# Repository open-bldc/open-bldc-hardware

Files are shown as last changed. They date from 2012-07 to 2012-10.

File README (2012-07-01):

This project aims to create a fully open-source Brushless Drive Controller.

This repository contains all current and past hardware designs. Please refer to the open-bldc repository for the source code.

Licensing
---------
All sourcecode is licensed under GPL version 3 or later, all circuitry designs
and pcb layouts are available as original source files and licensed under
CreativeCommons BY-SA 3.0.

Feel free to use everything here as you wish! :)

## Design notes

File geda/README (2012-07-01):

-------------------------------------------------------------------------------
README
-------------------------------------------------------------------------------

This is an effort to re-implement the Open-BLDC hardware descriptions
(schematics and PCB layouts) using the open-source tools gEDA/pcb.

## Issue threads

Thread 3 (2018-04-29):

modular ESC

mkeyno, 2018-04-29:
Hi, sorry to open ticket for my question , actually I intend to made modular ESC in way that controller + gate driver is separated from Mosfets pcb , hence I could increase module ampere by adding parallel Mosfet in the Mosfets pcb, I really appreciated to have your advise or if you know open HW/SW sources let me know

jegb, 2018-04-29:
you could break the modules down as in[ this NXP paper ](https://www.nxp.com/docs/en/user-guide/3PHLVPSUM.pdf)

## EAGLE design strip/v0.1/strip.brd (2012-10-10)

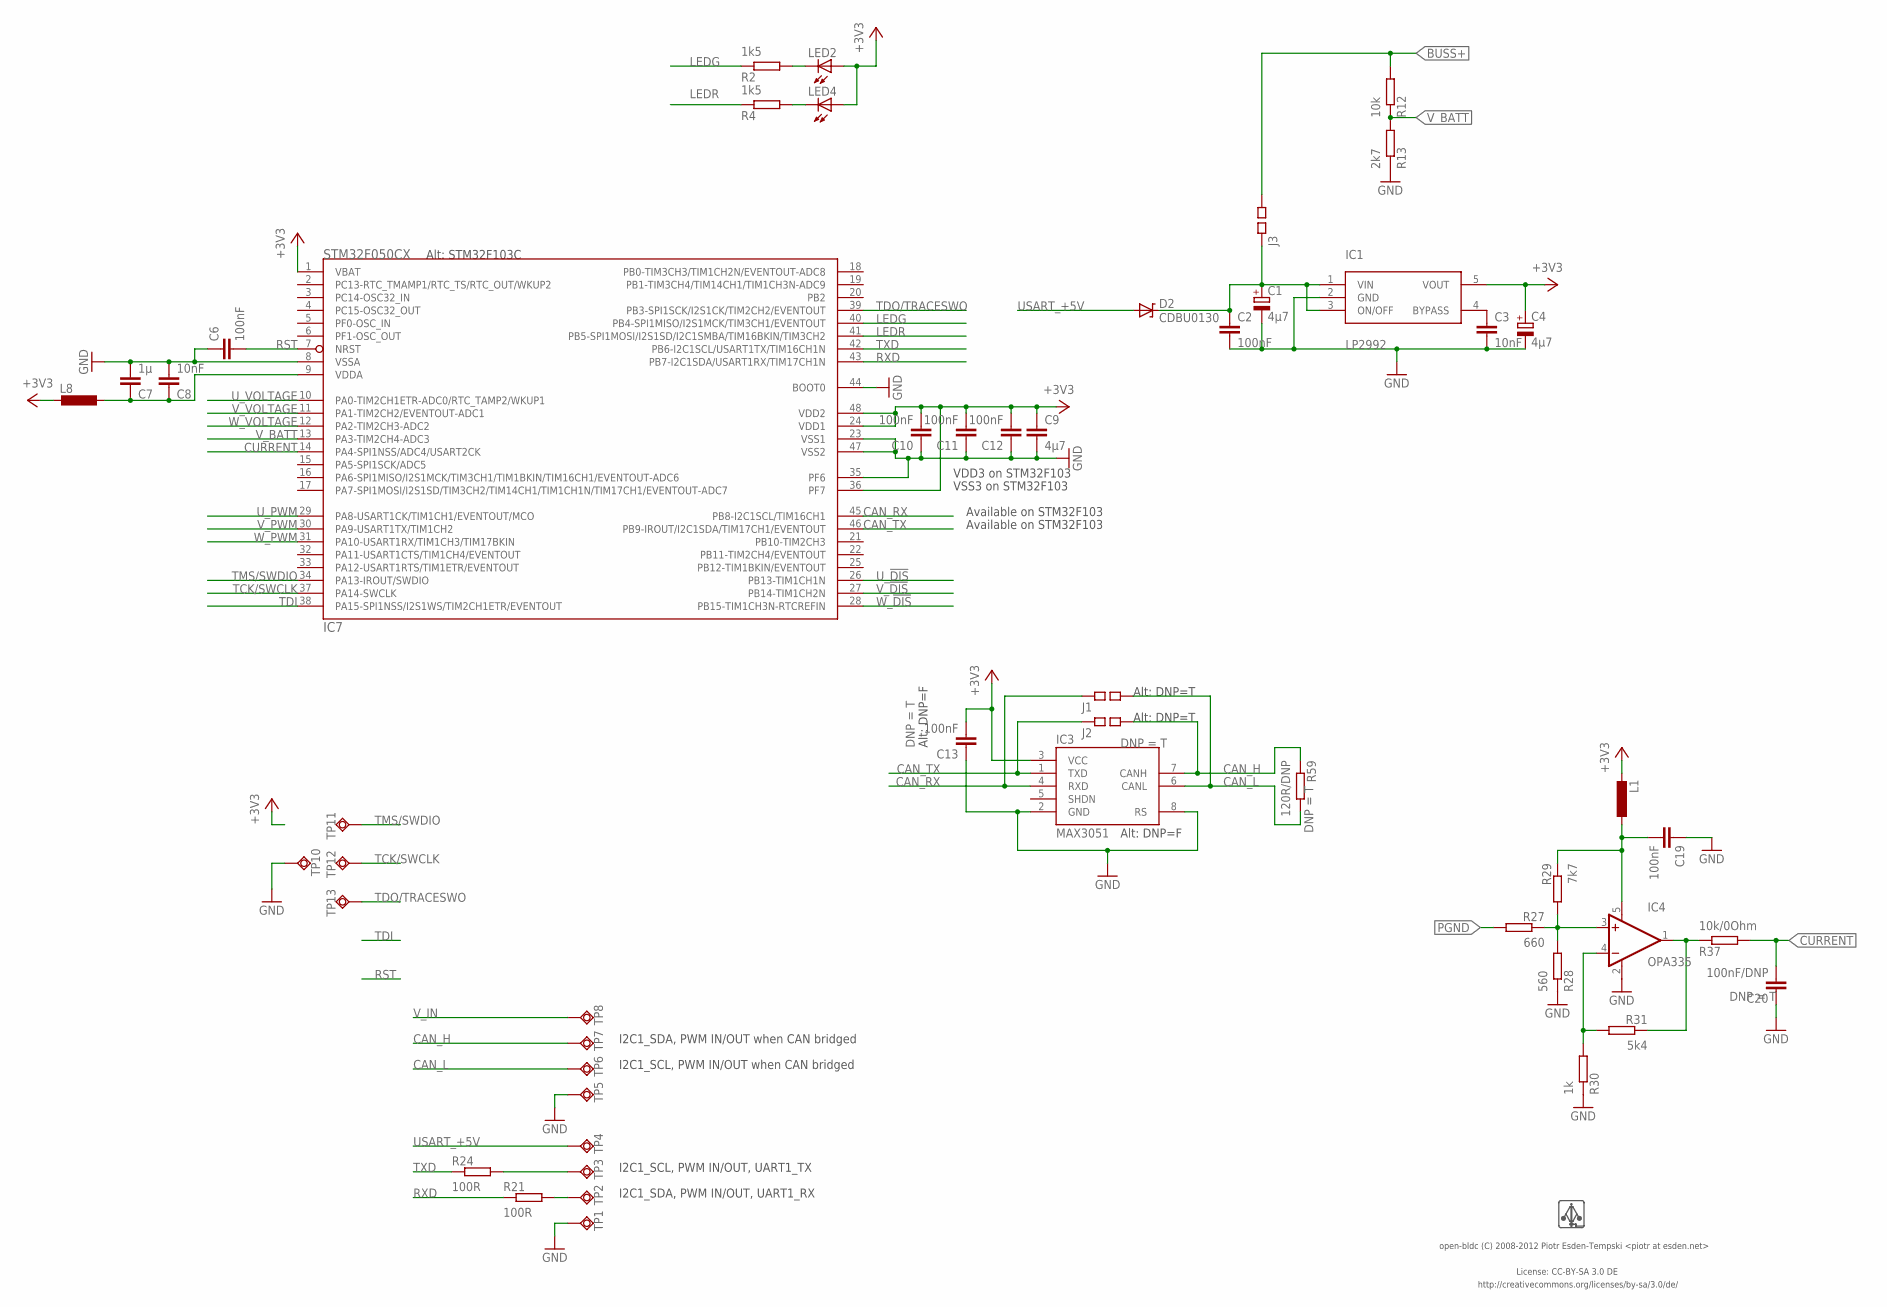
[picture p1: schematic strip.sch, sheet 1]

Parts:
C1, C4: 4µ7; 0805-POL-CAP; PARTNO cap-cer-0805-4u7-16v
C2, C6, C10, C11, C12, C13, C19: 100nF; 0402-CAP; PARTNO cap-cer-0402-100n
C3, C8: 10nF; 0402-CAP; PARTNO cap-cer-0402-10n
C7: 1µ; 0402-CAP; PARTNO cap-cer-0402-1u
C9: 4µ7; 0805-CAP; PARTNO cap-cer-0805-4u7
C20: 100nF/DNP; 0402-CAP; PARTNO cap-cer-0402-100n
D2: CDBU0130; 0603-DIO; PARTNO diode-0603
IC1: LP2992; SOT23-5; PARTNO vreg-sot-23-5-3v3
IC3: MAX3051; SO8; PARTNO ic-so8-can-3v3
IC4: OPA335; SOT23-5; PARTNO ic-sot-23-5-opamp
IC7: STM32F050CX; LQFP48; PARTNO mcu-lqfp-48-stm32f05
J1, J2, J3: SQ_JMP-0402; 0402-SQJMP; PARTNO res-0402-0
L1, L8: INDUCTOR-0603; 0603-IND; PARTNO ferrite-0603-600ohm
LED2: GREEN; 0402-LED; PARTNO led-0402-green
LED4: RED; 0402-LED; PARTNO led-0402-green
R2, R4: 1k5; 0402-RES; PARTNO res-0402-1k5
R12: 10k; 0402-RES; PARTNO res-0402-10k
R13: 2k7; 0402-RES; PARTNO res-0402-2k7
R21, R24: 100R; 0402-RES; PARTNO res-0402-100
R27: 660; 0402-RES; PARTNO res-0402-665
R28: 560; 0402-RES; PARTNO res-0402-560
R29: 7k7; 0402-RES; PARTNO res-0402-7k68
R30: 1k; 0402-RES; PARTNO res-0402-1k
R31: 5k4; 0402-RES; PARTNO res-0402-5k36
R37: 10k/0Ohm; 0402-RES; PARTNO res-0402-0
R59: 120R/DNP; 0402-RES; PARTNO res-0402-60.4
TP1, TP2, TP3, TP4, TP5, TP6, TP7, TP8: TPSQTP20SQ; TP20SQ; PARTNO *
TP10, TP11, TP12, TP13: TPSQTP11SQ; TP11SQ; PARTNO *
U$1: LOGO; LOGO_SILK_SMALL; PARTNO *

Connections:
+3V3: C4.+, C9.P$1 (1), C10.P$2 (2), C11.P$2 (2), C12.P$2 (2), C13.P$2 (2), IC1.5 (VOUT), IC3.3 (VCC), IC7.1 (VBAT), IC7.24 (VDD1), IC7.36 (PF7), IC7.48 (VDD2), L1.P$2 (2), L8.P$2 (2), LED2.A, LED4.A
BUSS+: J3.P$2 (2), R12.P$2 (2); also elsewhere on the board
CAN_H: IC3.7 (CANH), J2.P$2 (2), R59.P$1 (1), TP7.TP
CAN_L: IC3.6 (CANL), J1.P$2 (2), R59.P$2 (2), TP6.TP
CAN_RX: IC3.4 (RXD), IC7.45 (PB8-I2C1SCL/TIM16CH1), J1.P$1 (1)
CAN_TX: IC3.1 (TXD), IC7.46 (PB9-IROUT/I2C1SDA/TIM17CH1/EVENTOUT), J2.P$1 (1)
CURRENT: C20.P$2 (2), IC7.14 (PA4-SPI1NSS/ADC4/USART2CK), R37.P$2 (2)
CURRENT_RAW: IC4.1 (OUT), R31.P$1 (1), R37.P$1 (1)
GND: C1.-, C2.P$2 (2), C3.P$2 (2), C4.-, C6.P$1 (1), C7.P$2 (2), C8.P$2 (2), C9.P$2 (2), C10.P$1 (1), C11.P$1 (1), C12.P$1 (1), C13.P$1 (1), C19.P$1 (1), C20.P$1 (1), IC1.2 (GND), IC3.2 (GND), IC3.8 (RS), IC4.2 (V-), IC7.8 (VSSA), IC7.23 (VSS1), IC7.35 (PF6), IC7.44 (BOOT0), IC7.47 (VSS2), R13.P$1 (1), R28.P$1 (1), R30.P$1 (1), TP1.TP, TP5.TP, TP10.TP; also elsewhere on the board
LEDG: IC7.40 (PB4-SPI1MISO/I2S1MCK/TIM3CH1/EVENTOUT), R2.P$1 (1)
LEDR: IC7.41 (PB5-SPI1MOSI/I2S1SD/I2C1SMBA/TIM16BKIN/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), R4.P$1 (1)
unnamed: LED4.C, R4.P$2 (2)
unnamed: R21.P$2 (2), TP2.TP
unnamed: C19.P$2 (2), IC4.5 (V+), L1.P$1 (1), R29.P$1 (1)
unnamed: LED2.C, R2.P$2 (2)
unnamed: IC4.3 (+IN), R27.P$1 (1), R28.P$2 (2), R29.P$2 (2)
unnamed: IC4.4 (-IN), R30.P$2 (2), R31.P$2 (2)
unnamed: R24.P$2 (2), TP3.TP
unnamed: C3.P$1 (1), IC1.4 (BYPASS)
PGND: R27.P$2 (2); also elsewhere on the board
RST: C6.P$2 (2), IC7.7 (NRST)
RXD: IC7.43 (PB7-I2C1SDA/USART1RX/TIM17CH1N), R21.P$1 (1)
TCK/SWCLK: IC7.37 (PA14-SWCLK), TP12.TP
TDI: IC7.38 (PA15-SPI1NSS/I2S1WS/TIM2CH1ETR/EVENTOUT)
TDO/TRACESWO: IC7.39 (PB3-SPI1SCK/I2S1CK/TIM2CH2/EVENTOUT), TP13.TP
TMS/SWDIO: IC7.34 (PA13-IROUT/SWDIO), TP11.TP
TXD: IC7.42 (PB6-I2C1SCL/USART1TX/TIM16CH1N), R24.P$1 (1)
USART_+5V: D2.A, TP4.TP
U_!DIS: IC7.26 (PB13-TIM1CH1N); also elsewhere on the board
U_PWM: IC7.29 (PA8-USART1CK/TIM1CH1/EVENTOUT/MCO); also elsewhere on the board
U_VOLTAGE: IC7.10 (PA0-TIM2CH1ETR-ADC0/RTC_TAMP2/WKUP1); also elsewhere on the board
VDDA: C7.P$1 (1), C8.P$1 (1), IC7.9 (VDDA), L8.P$1 (1)
V_!DIS: IC7.27 (PB14-TIM1CH2N); also elsewhere on the board
V_BATT: IC7.13 (PA3-TIM2CH4-ADC3), R12.P$1 (1), R13.P$2 (2)
V_IN: C1.+, C2.P$1 (1), D2.C, IC1.1 (VIN), IC1.3 (ON/OFF), J3.P$1 (1), TP8.TP
V_PWM: IC7.30 (PA9-USART1TX/TIM1CH2); also elsewhere on the board
V_VOLTAGE: IC7.11 (PA1-TIM2CH2/EVENTOUT-ADC1); also elsewhere on the board
W_!DIS: IC7.28 (PB15-TIM1CH3N-RTCREFIN); also elsewhere on the board
W_PWM: IC7.31 (PA10-USART1RX/TIM1CH3/TIM17BKIN); also elsewhere on the board
W_VOLTAGE: IC7.12 (PA2-TIM2CH3-ADC2); also elsewhere on the board

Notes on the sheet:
License: CC-BY-SA 3.0 DE
http://creativecommons.org/licenses/by-sa/3.0/de/
open-bldc (C) 2008-2012 Piotr Esden-Tempski <piotr at esden.net>
VDD3 on STM32F103
VSS3 on STM32F103
Available on STM32F103
Alt: STM32F103C
Alt: DNP=T
Alt: DNP=F
I2C1_SDA, PWM IN/OUT when CAN bridged
I2C1_SCL, PWM IN/OUT when CAN bridged
I2C1_SCL, PWM IN/OUT, UART1_TX
I2C1_SDA, PWM IN/OUT, UART1_RX

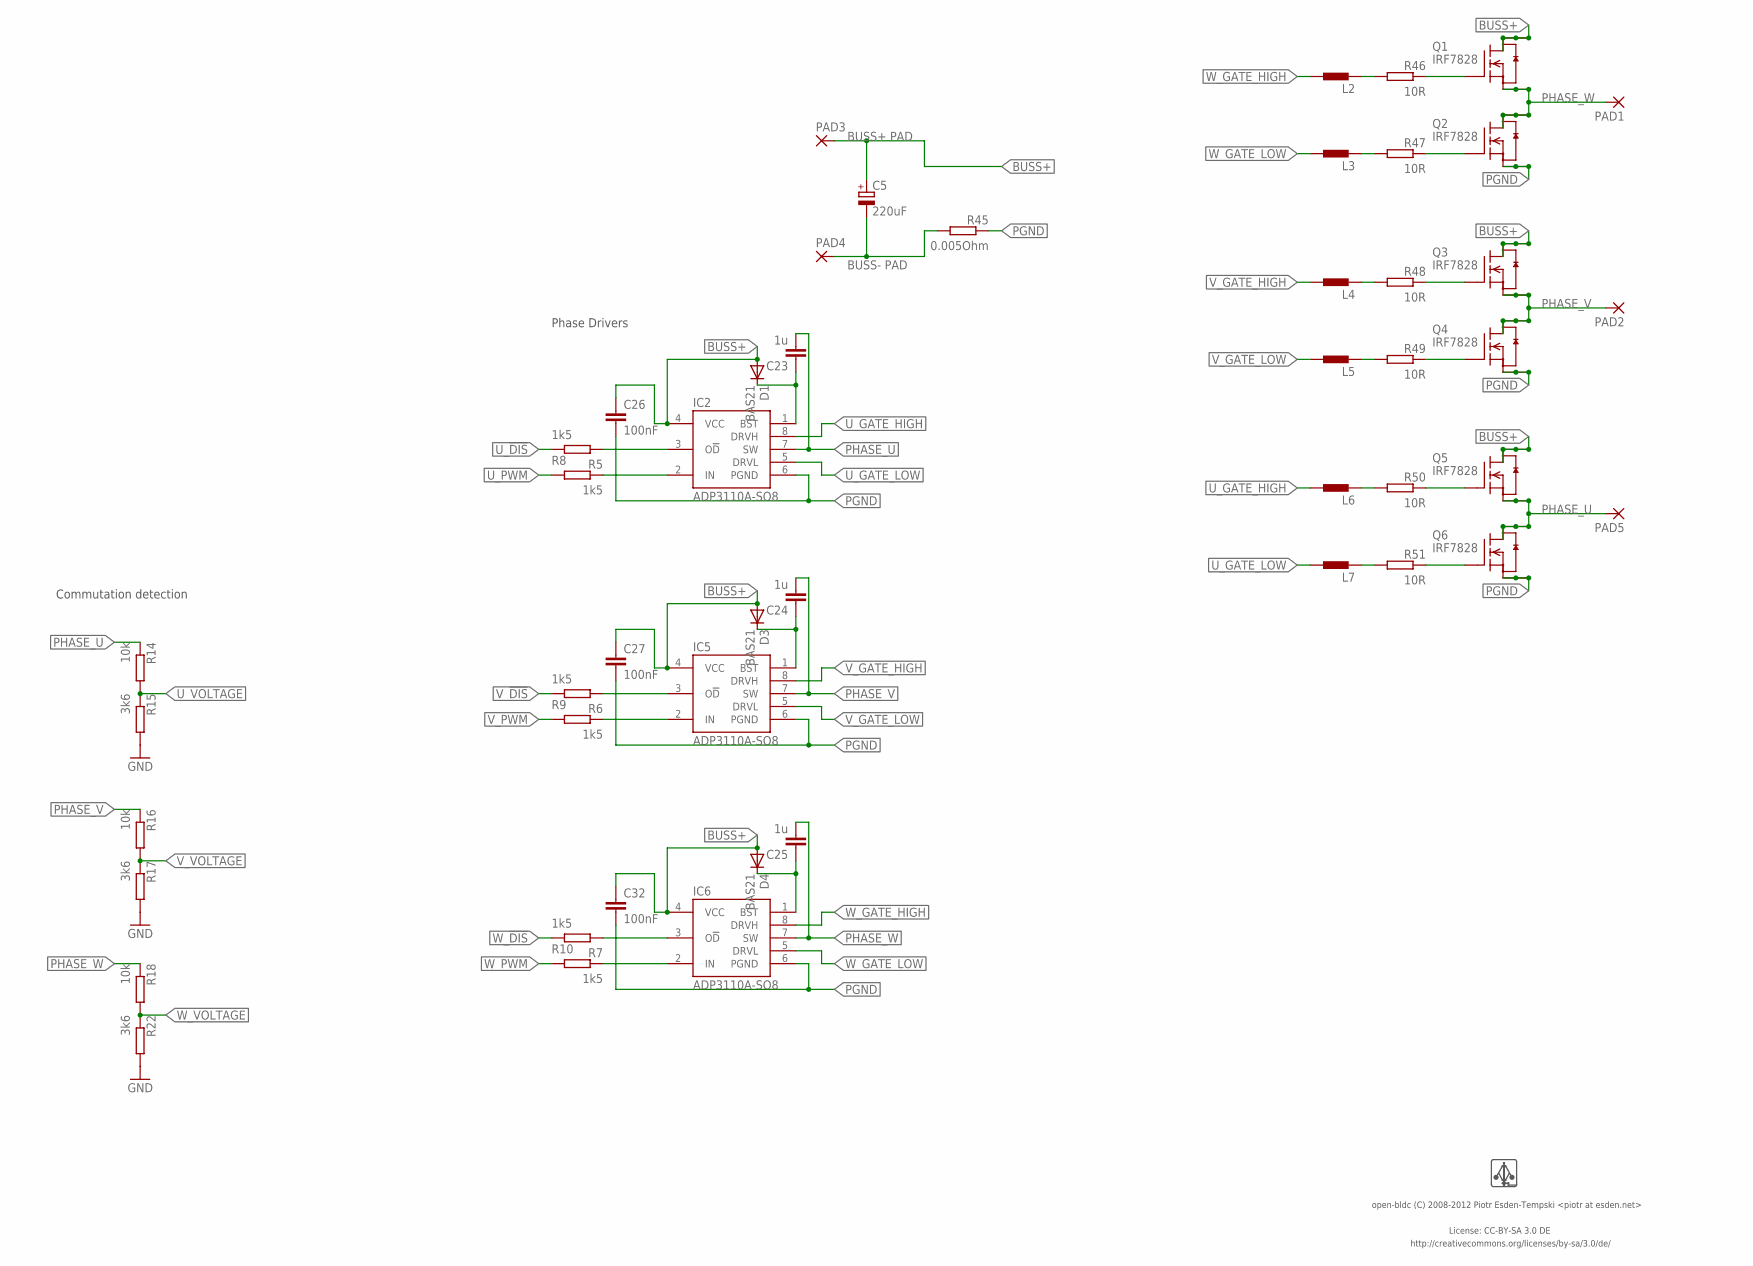
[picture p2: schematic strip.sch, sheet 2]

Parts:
C5: 220uF; 7343/D; PARTNO cap-tan-D-220u-16v
C23, C24, C25: 1u; 0603-CAP; PARTNO cap-tan-0603-1u
C26, C27, C32: 100nF; 0402-CAP; PARTNO cap-cer-0402-100n
D1, D3, D4: BAS21; SOD-123-DIO; PARTNO diode-sod-123
IC2, IC5, IC6: ADP3110A-SO8; SO8; PARTNO ic-so8-mosfet-driver-buck
L2, L3, L4, L5, L6, L7: INDUCTOR-0402; 0402-IND; PARTNO res-0402-0
PAD1, PAD2, PAD3, PAD4, PAD5: SMD5; SMD2,54-5,08; PARTNO *
Q1, Q2, Q3, Q4, Q5, Q6: IRF7828; SO8; PARTNO ic-so8-mosfet-n-ch-30v-15a
R5, R6, R7, R8, R9, R10: 1k5; 0402-RES; PARTNO res-0402-1k5
R14, R16, R18: 10k; 0402-RES; PARTNO res-0402-10k
R15, R17, R22: 3k6; 0402-RES; PARTNO res-0402-3k6
R45: 0.005Ohm; 1206-RES; PARTNO res-1206-0005
R46, R47, R48, R49, R50, R51: 10R; 0402-RES; PARTNO res-0402-10
U$2: LOGO; LOGO_SILK_SMALL; PARTNO *

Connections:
BUSS+: C5.+, C26.P$1 (1), C27.P$1 (1), C32.P$1 (1), D1.A, D3.A, D4.A, IC2.4 (VCC), IC5.4 (VCC), IC6.4 (VCC), PAD3.1, Q1.5 (D1), Q1.6 (D2), Q1.7 (D3), Q1.8 (D4), Q3.5 (D1), Q3.6 (D2), Q3.7 (D3), Q3.8 (D4), Q5.5 (D1), Q5.6 (D2), Q5.7 (D3), Q5.8 (D4); also elsewhere on the board
GND: C5.-, PAD4.1, R15.P$2 (2), R17.P$2 (2), R22.P$2 (2), R45.P$2 (2); also elsewhere on the board
unnamed: C23.P$1 (1), D1.C, IC2.1 (BST)
unnamed: C24.P$1 (1), D3.C, IC5.1 (BST)
unnamed: C25.P$1 (1), D4.C, IC6.1 (BST)
unnamed: L2.P$2 (2), R46.P$2 (2)
unnamed: L3.P$2 (2), R47.P$2 (2)
unnamed: L4.P$2 (2), R48.P$2 (2)
unnamed: L5.P$2 (2), R49.P$2 (2)
unnamed: L6.P$2 (2), R50.P$2 (2)
unnamed: L7.P$2 (2), R51.P$2 (2)
unnamed: Q1.4 (G), R46.P$1 (1)
unnamed: Q2.4 (G), R47.P$1 (1)
unnamed: Q3.4 (G), R48.P$1 (1)
unnamed: Q4.4 (G), R49.P$1 (1)
unnamed: Q5.4 (G), R50.P$1 (1)
unnamed: Q6.4 (G), R51.P$1 (1)
PGND: C26.P$2 (2), C27.P$2 (2), C32.P$2 (2), IC2.6 (PGND), IC5.6 (PGND), IC6.6 (PGND), Q2.1 (S3), Q2.2 (S2), Q2.3 (S1), Q4.1 (S3), Q4.2 (S2), Q4.3 (S1), Q6.1 (S3), Q6.2 (S2), Q6.3 (S1), R45.P$1 (1); also elsewhere on the board
PHASE_U: C23.P$2 (2), IC2.7 (SW), PAD5.1, Q5.1 (S3), Q5.2 (S2), Q5.3 (S1), Q6.5 (D1), Q6.6 (D2), Q6.7 (D3), Q6.8 (D4), R14.P$1 (1)
PHASE_V: C24.P$2 (2), IC5.7 (SW), PAD2.1, Q3.1 (S3), Q3.2 (S2), Q3.3 (S1), Q4.5 (D1), Q4.6 (D2), Q4.7 (D3), Q4.8 (D4), R16.P$1 (1)
PHASE_W: C25.P$2 (2), IC6.7 (SW), PAD1.1, Q1.1 (S3), Q1.2 (S2), Q1.3 (S1), Q2.5 (D1), Q2.6 (D2), Q2.7 (D3), Q2.8 (D4), R18.P$1 (1)
U_!DIS: R8.P$1 (1); also elsewhere on the board
U_!DIS!1: IC2.3 (O!D), R8.P$2 (2)
U_GATE_HIGH: IC2.8 (DRVH), L6.P$1 (1)
U_GATE_LOW: IC2.5 (DRVL), L7.P$1 (1)
U_PWM: R5.P$2 (2); also elsewhere on the board
U_PWM1: IC2.2 (IN), R5.P$1 (1)
U_VOLTAGE: R14.P$2 (2), R15.P$1 (1); also elsewhere on the board
V_!DIS: R9.P$1 (1); also elsewhere on the board
V_!DIS!1: IC5.3 (O!D), R9.P$2 (2)
V_GATE_HIGH: IC5.8 (DRVH), L4.P$1 (1)
V_GATE_LOW: IC5.5 (DRVL), L5.P$1 (1)
V_PWM: R6.P$2 (2); also elsewhere on the board
V_PWM1: IC5.2 (IN), R6.P$1 (1)
V_VOLTAGE: R16.P$2 (2), R17.P$1 (1); also elsewhere on the board
W_!DIS: R10.P$1 (1); also elsewhere on the board
W_!DIS1: IC6.3 (O!D), R10.P$2 (2)
W_GATE_HIGH: IC6.8 (DRVH), L2.P$1 (1)
W_GATE_LOW: IC6.5 (DRVL), L3.P$1 (1)
W_PWM: R7.P$2 (2); also elsewhere on the board
W_PWM1: IC6.2 (IN), R7.P$1 (1)
W_VOLTAGE: R18.P$2 (2), R22.P$1 (1); also elsewhere on the board

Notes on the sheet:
Phase Drivers
Commutation detection
BUSS+ PAD
BUSS- PAD
License: CC-BY-SA 3.0 DE
http://creativecommons.org/licenses/by-sa/3.0/de/
open-bldc (C) 2008-2012 Piotr Esden-Tempski <piotr at esden.net>

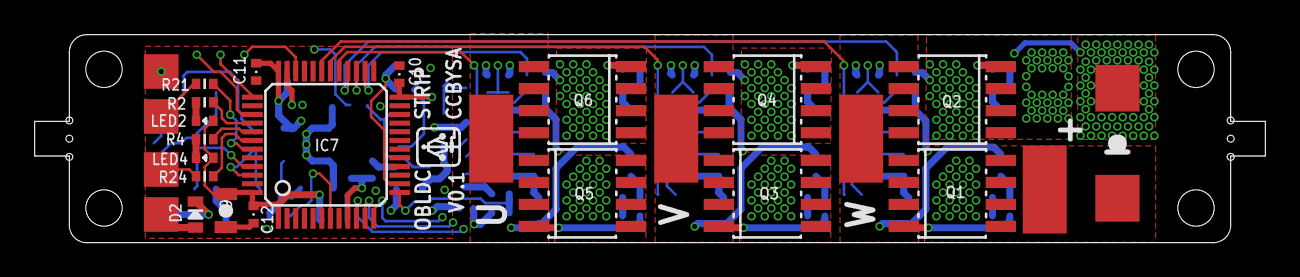
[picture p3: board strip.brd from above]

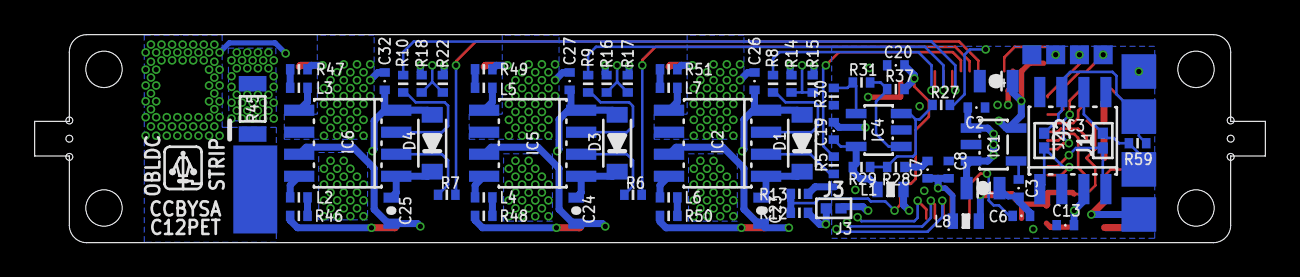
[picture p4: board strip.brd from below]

Board: 4 copper layers, 71.0 x 12.0 mm, 102 parts (74 on the bottom side), 69 nets.

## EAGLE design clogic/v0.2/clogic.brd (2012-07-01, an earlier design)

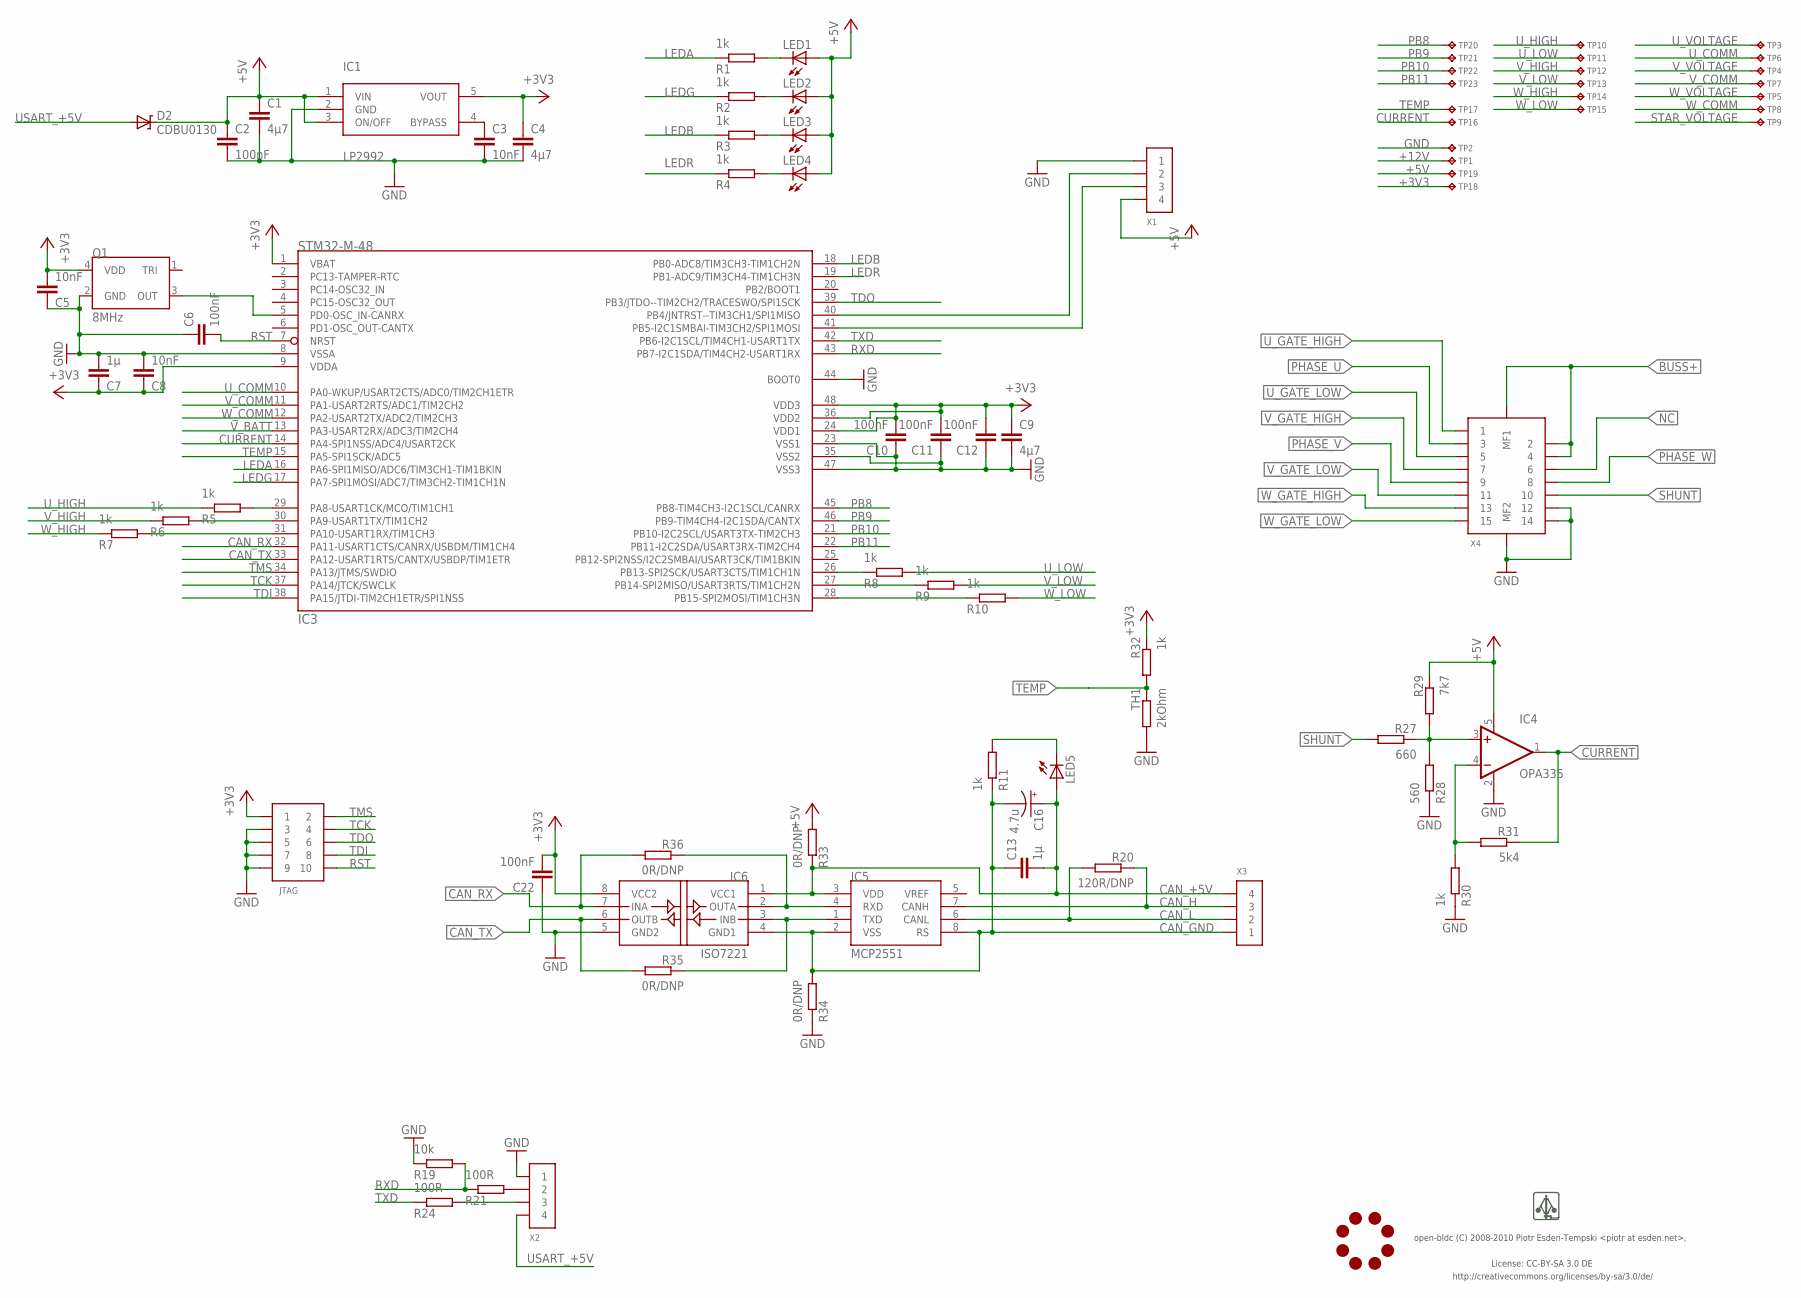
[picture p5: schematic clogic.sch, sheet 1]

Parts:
C1, C4, C9: 4µ7; 0603-CAP
C2, C6, C10, C11, C12, C22: 100nF; 0603-CAP
C3, C5, C8: 10nF; 0603-CAP
C7, C13: 1µ; 0603-CAP
C16: 4.7u; CAP_0805TANT_F95
D2: CDBU0130; 0603-LED
IC1: LP2992; SOT23-5
IC3: STM32-M-48; LQFP48
IC4: OPA335; SOT23-5
IC5: MCP2551; SO8
IC6: ISO7221; SO8
JL1: JOBY_LOGO-6MIL; JOBY_LOGO_6MIL
JTAG: CONN_5-2-FTSH-V; FTSH-105-DV
LED1: AMBER; 0603-LED
LED2: GREEN; 0603-LED
LED3: BLUE; 0603-LED
LED4: RED; 0603-LED
LED5: WHITE; 0603-LED
Q1: 8MHz; ASE_OSCILLATOR
R1, R2, R3, R4, R5, R6, R7, R8, R9, R10, R11, R30, R32: 1k; 0603-RES
R19: 10k; 0603-RES
R20: 120R/DNP; 0603-RES
R21, R24: 100R; 0603-RES
R27: 660; 0603-RES
R28: 560; 0603-RES
R29: 7k7; 0603-RES
R31: 5k4; 0603-RES
R33, R34, R35, R36: 0R/DNP; 0603-RES
TH1: 2kOhm; 0603-RES
TP1, TP2, TP3, TP4, TP5, TP6, TP7, TP8, TP9, TP10, TP11, TP12, TP13, TP14, TP15, TP16, TP17, TP18, TP19, TP20, TP21, TP22, TP23: TP-09RSMD; TP09R
U$1: LOGO
X1, X2, X3: CONN_4-1-53261; PB-53261-04
X4: CONN_15-2-2MT-DF9; DF9-15

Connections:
+3V3: C4.P$1 (1), C5.P$2 (2), C7.P$1 (1), C8.P$1 (1), C9.P$1 (1), C10.P$2 (2), C11.P$2 (2), C12.P$2 (2), C22.P$2 (2), IC1.5 (VOUT), IC3.1 (VBAT), IC3.9 (VDDA), IC3.24 (VDD1), IC3.36 (VDD2), IC3.48 (VDD3), IC6.8 (VCC2), JTAG.1, Q1.4 (VDD), R32.P$1 (1), TP18.P$1
+5V: C1.P$1 (1), C2.P$1 (1), D2.C, IC1.1 (VIN), IC1.3 (ON/OFF), IC4.5 (V+), LED1.A, LED2.A, LED3.A, LED4.A, R29.P$1 (1), R33.P$2 (2), TP19.P$1, X1.4; also elsewhere on the board
+12V: TP1.P$1; also elsewhere on the board
A: IC3.40 (PB4/JNTRST--TIM3CH1/SPI1MISO), X1.2
B: IC3.41 (PB5-I2C1SMBAI-TIM3CH2/SPI1MOSI), X1.3
BUSS+: X4.2, X4.4, X4.MF1; also elsewhere on the board
CAN_+5V: C13.P$2 (2), C16.P$1 (+), IC5.3 (VDD), IC6.1 (VCC1), LED5.A, R33.P$1 (1), X3.4
CAN_GND: C13.P$1 (1), C16.P$2 (-), IC5.2 (VSS), IC5.8 (RS), IC6.4 (GND1), R11.P$1 (1), R34.P$2 (2), X3.1
CAN_H: IC5.7 (CANH), R20.P$1 (1), X3.3
CAN_L: IC5.6 (CANL), R20.P$2 (2), X3.2
CAN_RX: IC3.32 (PA11-USART1CTS/CANRX/USBDM/TIM1CH4), IC6.7 (INA), R36.P$2 (2)
CAN_TX: IC3.33 (PA12-USART1RTS/CANTX/USBDP/TIM1ETR), IC6.6 (OUTB), R35.P$2 (2)
CURRENT: IC3.14 (PA4-SPI1NSS/ADC4/USART2CK), IC4.1 (OUT), R31.P$1 (1), TP16.P$1
GND: C1.P$2 (2), C2.P$2 (2), C3.P$2 (2), C4.P$2 (2), C5.P$1 (1), C6.P$1 (1), C7.P$2 (2), C8.P$2 (2), C9.P$2 (2), C10.P$1 (1), C11.P$1 (1), C12.P$1 (1), C22.P$1 (1), IC1.2 (GND), IC3.8 (VSSA), IC3.23 (VSS1), IC3.35 (VSS2), IC3.44 (BOOT0), IC3.47 (VSS3), IC4.2 (V-), IC6.5 (GND2), JTAG.3, JTAG.5, JTAG.7, JTAG.9, Q1.2 (GND), R19.P$1 (1), R28.P$1 (1), R30.P$1 (1), R34.P$1 (1), TH1.P$2 (2), TP2.P$1, X1.1, X2.1, X4.12, X4.14, X4.MF2; also elsewhere on the board
LEDA: IC3.16 (PA6-SPI1MISO/ADC6/TIM3CH1-TIM1BKIN), R1.P$1 (1)
LEDB: IC3.18 (PB0-ADC8/TIM3CH3-TIM1CH2N), R3.P$1 (1)
LEDG: IC3.17 (PA7-SPI1MOSI/ADC7/TIM3CH2-TIM1CH1N), R2.P$1 (1)
LEDR: IC3.19 (PB1-ADC9/TIM3CH4-TIM1CH3N), R4.P$1 (1)
unnamed: LED5.C, R11.P$2 (2)
unnamed: LED1.C, R1.P$2 (2)
unnamed: LED4.C, R4.P$2 (2)
unnamed: LED3.C, R3.P$2 (2)
unnamed: R21.P$2 (2), X2.2
unnamed: LED2.C, R2.P$2 (2)
unnamed: IC4.3 (+IN), R27.P$1 (1), R28.P$2 (2), R29.P$2 (2)
unnamed: IC4.4 (-IN), R30.P$2 (2), R31.P$2 (2)
unnamed: IC5.1 (TXD), IC6.3 (INB), R35.P$1 (1)
unnamed: IC5.4 (RXD), IC6.2 (OUTA), R36.P$1 (1)
unnamed: R24.P$2 (2), X2.3
unnamed: C3.P$1 (1), IC1.4 (BYPASS)
unnamed: IC3.26 (PB13-SPI2SCK/USART3CTS/TIM1CH1N), R8.P$1 (1)
unnamed: IC3.27 (PB14-SPI2MISO/USART3RTS/TIM1CH2N), R9.P$1 (1)
unnamed: IC3.28 (PB15-SPI2MOSI/TIM1CH3N), R10.P$1 (1)
unnamed: IC3.5 (PD0-OSC_IN-CANRX), Q1.3 (OUT)
unnamed: IC3.29 (PA8-USART1CK/MCO/TIM1CH1), R5.P$2 (2)
unnamed: IC3.30 (PA9-USART1TX/TIM1CH2), R6.P$2 (2)
unnamed: IC3.31 (PA10-USART1RX/TIM1CH3), R7.P$2 (2)
NC: X4.6
PB8: IC3.45 (PB8-TIM4CH3-I2C1SCL/CANRX), TP20.P$1
PB9: IC3.46 (PB9-TIM4CH4-I2C1SDA/CANTX), TP21.P$1
PB10: IC3.21 (PB10-I2C2SCL/USART3TX-TIM2CH3), TP22.P$1
PB11: IC3.22 (PB11-I2C2SDA/USART3RX-TIM2CH4), TP23.P$1
PHASE_U: X4.3; also elsewhere on the board
PHASE_V: X4.9; also elsewhere on the board
PHASE_W: X4.8; also elsewhere on the board
RST: C6.P$2 (2), IC3.7 (NRST), JTAG.10
RXD: IC3.43 (PB7-I2C1SDA/TIM4CH2-USART1RX), R19.P$2 (2), R21.P$1 (1)
SHUNT: R27.P$2 (2), X4.10
STAR_VOLTAGE: TP9.P$1; also elsewhere on the board
TCK: IC3.37 (PA14/JTCK/SWCLK), JTAG.4
TDI: IC3.38 (PA15/JTDI-TIM2CH1ETR/SPI1NSS), JTAG.8
TDO: IC3.39 (PB3/JTDO--TIM2CH2/TRACESWO/SPI1SCK), JTAG.6
TEMP: IC3.15 (PA5-SPI1SCK/ADC5), R32.P$2 (2), TH1.P$1 (1), TP17.P$1
TMS: IC3.34 (PA13/JTMS/SWDIO), JTAG.2
TXD: IC3.42 (PB6-I2C1SCL/TIM4CH1-USART1TX), R24.P$1 (1)
USART_+5V: D2.A, X2.4
U_COMM: IC3.10 (PA0-WKUP/USART2CTS/ADC0/TIM2CH1ETR), TP6.P$1; also elsewhere on the board
U_GATE_HIGH: X4.1; also elsewhere on the board
U_GATE_LOW: X4.5; also elsewhere on the board
U_HIGH: R5.P$1 (1), TP10.P$1; also elsewhere on the board
U_LOW: R8.P$2 (2), TP11.P$1; also elsewhere on the board
U_VOLTAGE: TP3.P$1; also elsewhere on the board
V_BATT: IC3.13 (PA3-USART2RX/ADC3/TIM2CH4); also elsewhere on the board
V_COMM: IC3.11 (PA1-USART2RTS/ADC1/TIM2CH2), TP7.P$1; also elsewhere on the board
V_GATE_HIGH: X4.7; also elsewhere on the board
V_GATE_LOW: X4.11; also elsewhere on the board
V_HIGH: R6.P$1 (1), TP12.P$1; also elsewhere on the board
V_LOW: R9.P$2 (2), TP13.P$1; also elsewhere on the board
V_VOLTAGE: TP4.P$1; also elsewhere on the board
W_COMM: IC3.12 (PA2-USART2TX/ADC2/TIM2CH3), TP8.P$1; also elsewhere on the board
W_GATE_HIGH: X4.13; also elsewhere on the board
W_GATE_LOW: X4.15; also elsewhere on the board
W_HIGH: R7.P$1 (1), TP14.P$1; also elsewhere on the board
W_LOW: R10.P$2 (2), TP15.P$1; also elsewhere on the board
W_VOLTAGE: TP5.P$1; also elsewhere on the board

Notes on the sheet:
License: CC-BY-SA 3.0 DE
http://creativecommons.org/licenses/by-sa/3.0/de/
open-bldc (C) 2008-2010 Piotr Esden-Tempski <piotr at esden.net>,

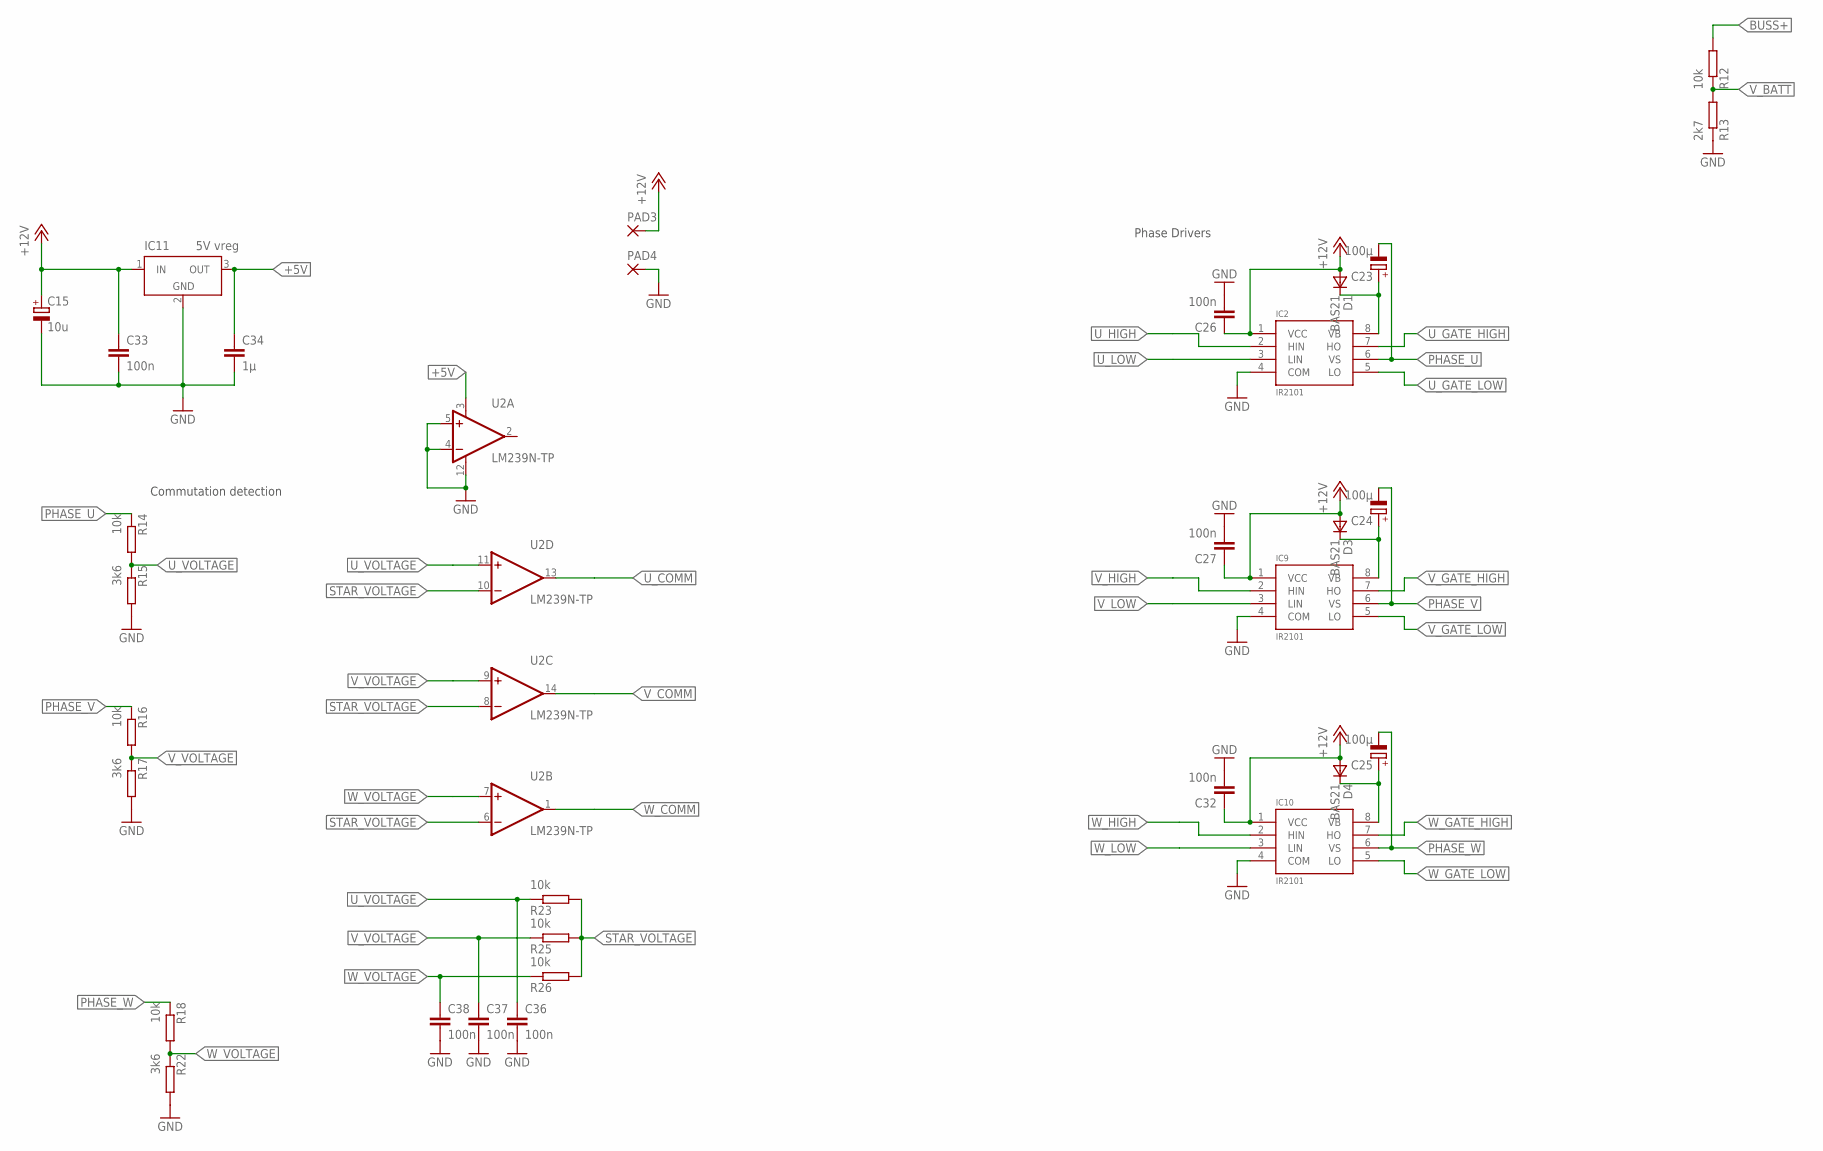
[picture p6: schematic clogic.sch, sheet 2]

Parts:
C15: 10u; 3528/B
C23, C24, C25: 100µ; 0805-POL-CAP
C26, C27, C32, C33, C36, C37, C38: 100n; 0603-CAP
C34: 1µ; 0603-CAP
D1, D3, D4: BAS21; SOT-23
IC2, IC9, IC10: IR2101; SO-8
IC11: 5V vreg; SOT223
PAD3, PAD4: SMD5; SMD2,54-5,08
R12, R14, R16, R18, R23, R25, R26: 10k; 0603-RES
R13: 2k7; 0603-RES
R15, R17, R22: 3k6; 0603-RES
U2: LM239N-TP; TSSOP_14

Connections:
+5V: C34.P$1 (1), IC11.3 (OUT), U2.3 (V+); also elsewhere on the board
+12V: C15.+, C26.P$1 (1), C27.P$1 (1), C32.P$1 (1), C33.P$1 (1), D1.3 (A), D3.3 (A), D4.3 (A), IC2.1 (VCC), IC9.1 (VCC), IC10.1 (VCC), IC11.1 (IN), PAD3.1; also elsewhere on the board
BUSS+: R12.P$2 (2); also elsewhere on the board
GND: C15.-, C26.P$2 (2), C27.P$2 (2), C32.P$2 (2), C33.P$2 (2), C34.P$2 (2), C36.P$2 (2), C37.P$2 (2), C38.P$2 (2), IC2.4 (COM), IC9.4 (COM), IC10.4 (COM), IC11.2 (GND), IC11.4 (GND), PAD4.1, R13.P$1 (1), R15.P$2 (2), R17.P$2 (2), R22.P$2 (2), U2.4 (-IN), U2.5 (+IN), U2.12 (V-); also elsewhere on the board
unnamed: C23.+, D1.1 (C), IC2.8 (VB)
unnamed: C24.+, D3.1 (C), IC9.8 (VB)
unnamed: C25.+, D4.1 (C), IC10.8 (VB)
PHASE_U: C23.-, IC2.6 (VS), R14.P$1 (1); also elsewhere on the board
PHASE_V: C24.-, IC9.6 (VS), R16.P$1 (1); also elsewhere on the board
PHASE_W: C25.-, IC10.6 (VS), R18.P$1 (1); also elsewhere on the board
STAR_VOLTAGE: R23.P$2 (2), R25.P$2 (2), R26.P$2 (2), U2.6 (-IN), U2.8 (-IN), U2.10 (-IN); also elsewhere on the board
U_COMM: U2.13 (OUT); also elsewhere on the board
U_GATE_HIGH: IC2.7 (HO); also elsewhere on the board
U_GATE_LOW: IC2.5 (LO); also elsewhere on the board
U_HIGH: IC2.2 (HIN); also elsewhere on the board
U_LOW: IC2.3 (LIN); also elsewhere on the board
U_VOLTAGE: C36.P$1 (1), R14.P$2 (2), R15.P$1 (1), R23.P$1 (1), U2.11 (+IN); also elsewhere on the board
V_BATT: R12.P$1 (1), R13.P$2 (2); also elsewhere on the board
V_COMM: U2.14 (OUT); also elsewhere on the board
V_GATE_HIGH: IC9.7 (HO); also elsewhere on the board
V_GATE_LOW: IC9.5 (LO); also elsewhere on the board
V_HIGH: IC9.2 (HIN); also elsewhere on the board
V_LOW: IC9.3 (LIN); also elsewhere on the board
V_VOLTAGE: C37.P$1 (1), R16.P$2 (2), R17.P$1 (1), R25.P$1 (1), U2.9 (+IN); also elsewhere on the board
W_COMM: U2.1 (OUT); also elsewhere on the board
W_GATE_HIGH: IC10.7 (HO); also elsewhere on the board
W_GATE_LOW: IC10.5 (LO); also elsewhere on the board
W_HIGH: IC10.2 (HIN); also elsewhere on the board
W_LOW: IC10.3 (LIN); also elsewhere on the board
W_VOLTAGE: C38.P$1 (1), R18.P$2 (2), R22.P$1 (1), R26.P$1 (1), U2.7 (+IN); also elsewhere on the board

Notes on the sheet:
Phase Drivers
Commutation detection

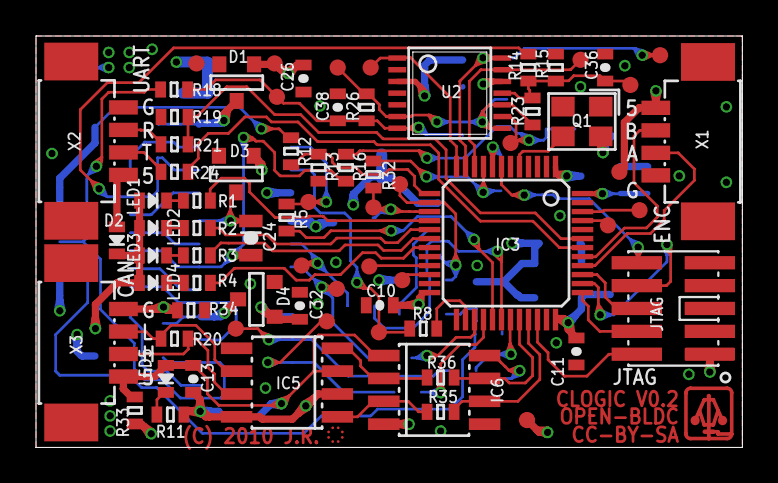
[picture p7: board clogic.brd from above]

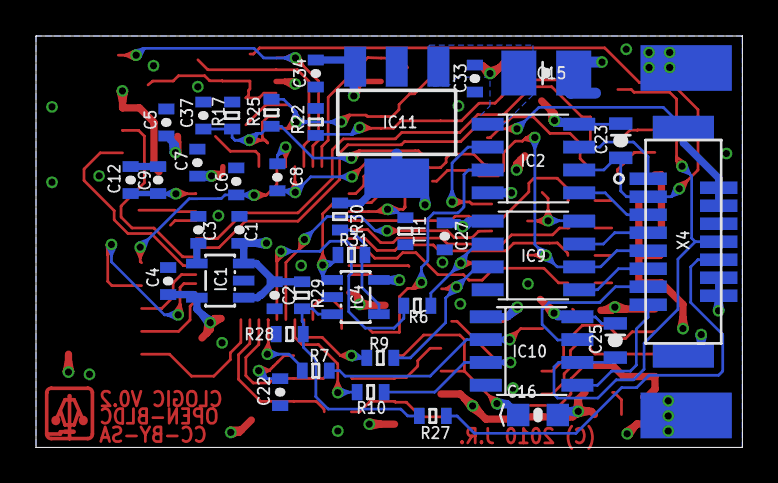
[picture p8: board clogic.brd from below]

Board: 4 copper layers, 39.2 x 22.9 mm, 117 parts (41 on the bottom side), 77 nets.

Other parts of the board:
DRILEGEND: DRILEGEND

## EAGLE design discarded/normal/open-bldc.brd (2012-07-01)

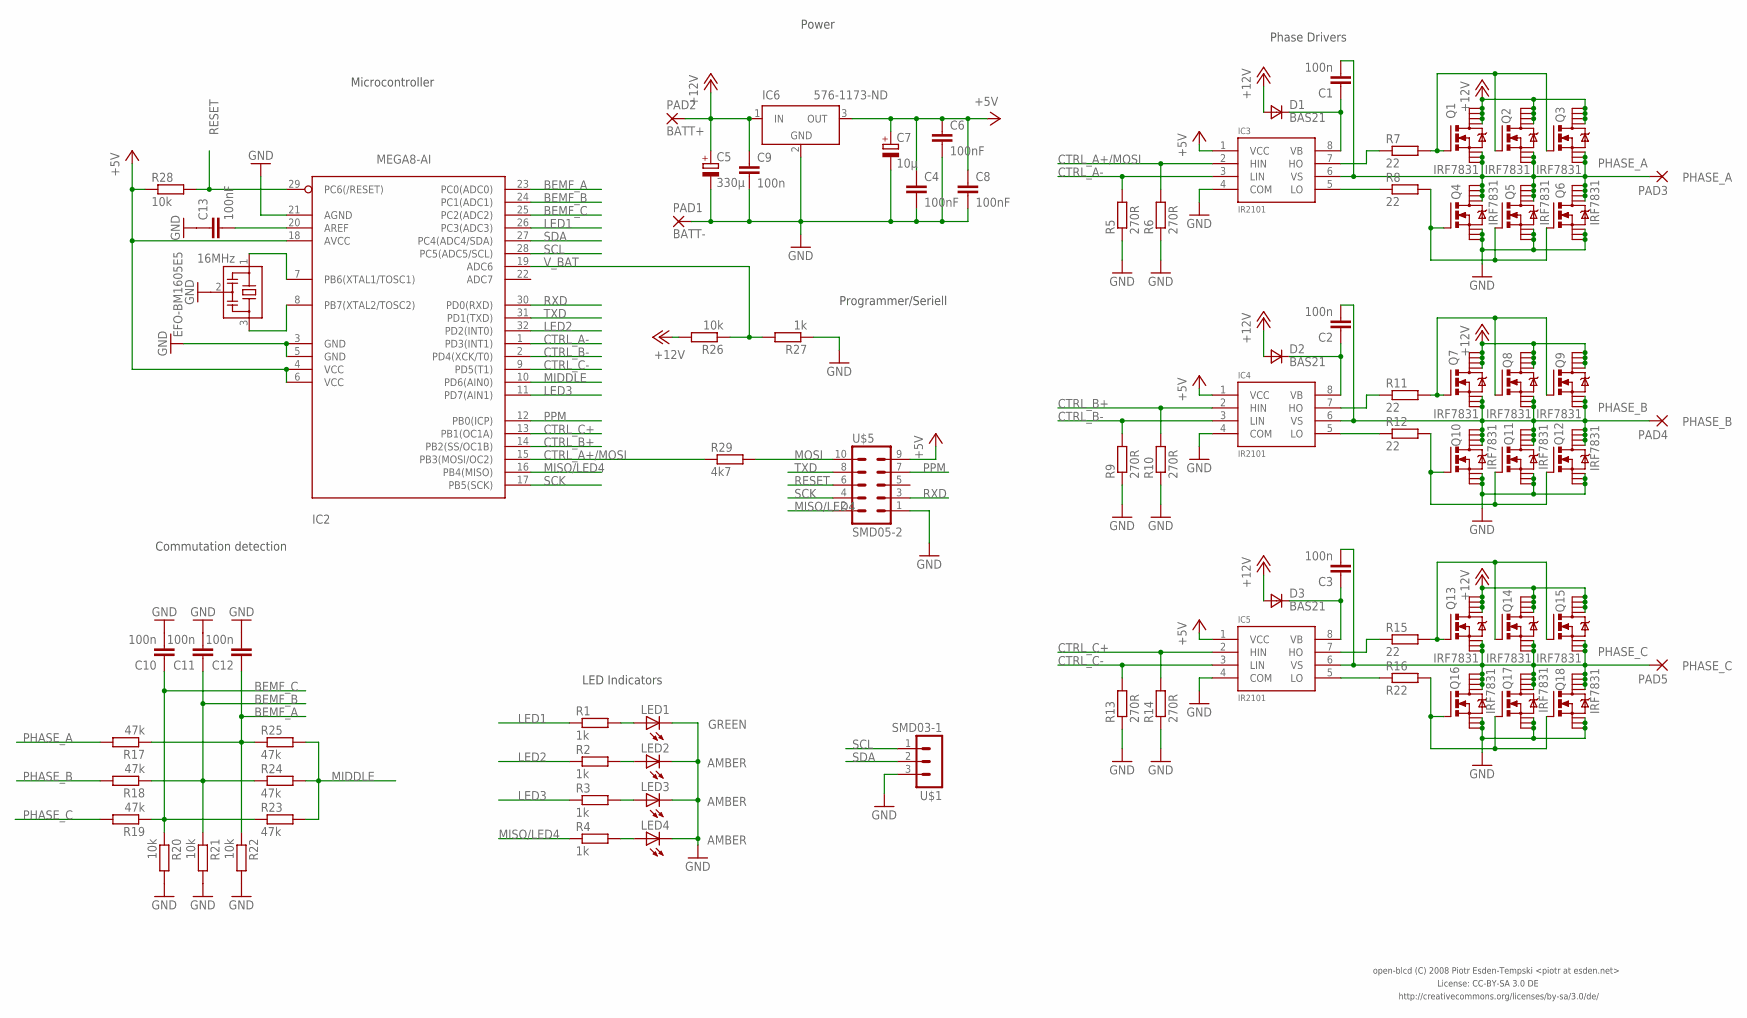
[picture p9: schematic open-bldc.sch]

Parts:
C1, C2, C3, C9, C10, C11, C12: 100n; C0603
C4, C6, C8, C13: 100nF; C0603
C5: 330µ; E3,5-8
C7: 10µ; D/7343-31R
D1, D2, D3: BAS21; SOT-23
EFO-BM1605E5: 16MHz; EFOBM
IC2: MEGA8-AI; TQFP32-08
IC3, IC4, IC5: IR2101; SO-8
IC6: 576-1173-ND; SOT223
LED1: GREEN; CHIP-LED0603
LED2, LED3, LED4: AMBER; CHIP-LED0603
PAD1: BATT-; SMD2,54-5,08
PAD2: BATT+; SMD2,54-5,08
PAD3: PHASE_A; SMD2,54-5,08
PAD4: PHASE_B; SMD2,54-5,08
PAD5: PHASE_C; SMD2,54-5,08
Q1, Q2, Q3, Q4, Q5, Q6, Q7, Q8, Q9, Q10, Q11, Q12, Q13, Q14, Q15, Q16, Q17, Q18: IRF7831; SO-08
R1, R2, R3, R4, R27: 1k; R0603
R5, R6, R9, R10, R13, R14: 270R; R0603
R7, R8, R11, R12, R15: 22; R0603
R16: R22; R0603
R17, R18, R19, R23, R24, R25: 47k; R0603
R20, R21, R22, R26, R28: 10k; R0603
R29: 4k7; R0603
U$1: SMD03-1
U$5: SMD05-2

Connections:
+5V: C4.1, C6.1, C7.+, C8.1, IC2.4 (VCC), IC2.6 (VCC), IC2.18 (AVCC), IC3.1 (VCC), IC4.1 (VCC), IC5.1 (VCC), IC6.3 (OUT), R28.1, U$5.9
+12V: C5.+, C9.1, D1.3 (A), D2.3 (A), D3.3 (A), IC6.1 (IN), PAD2.1, Q1.5 (D), Q1.6 (D), Q1.7 (D), Q1.8 (D), Q2.5 (D), Q2.6 (D), Q2.7 (D), Q2.8 (D), Q3.5 (D), Q3.6 (D), Q3.7 (D), Q3.8 (D), Q7.5 (D), Q7.6 (D), Q7.7 (D), Q7.8 (D), Q8.5 (D), Q8.6 (D), Q8.7 (D), Q8.8 (D), Q9.5 (D), Q9.6 (D), Q9.7 (D), Q9.8 (D), Q13.5 (D), Q13.6 (D), Q13.7 (D), Q13.8 (D), Q14.5 (D), Q14.6 (D), Q14.7 (D), Q14.8 (D), Q15.5 (D), Q15.6 (D), Q15.7 (D), Q15.8 (D), R26.2
BEMF_A: C12.1, IC2.23 (PC0(ADC0)), R17.1, R22.1, R25.1
BEMF_B: C11.1, IC2.24 (PC1(ADC1)), R18.1, R21.1, R24.1
BEMF_C: C10.1, IC2.25 (PC2(ADC2)), R19.1, R20.1, R23.1
CTRL_A+/MOSI: IC2.15 (PB3(MOSI/OC2)), IC3.2 (HIN), R6.2, R29.1
CTRL_A-: IC2.1 (PD3(INT1)), IC3.3 (LIN), R5.2
CTRL_B+: IC2.14 (PB2(SS/OC1B)), IC4.2 (HIN), R10.2
CTRL_B-: IC2.2 (PD4(XCK/T0)), IC4.3 (LIN), R9.2
CTRL_C+: IC2.13 (PB1(OC1A)), IC5.2 (HIN), R14.2
CTRL_C-: IC2.9 (PD5(T1)), IC5.3 (LIN), R13.2
GND: C4.2, C5.-, C6.2, C7.-, C8.2, C9.2, C10.2, C11.2, C12.2, C13.1, EFO-BM1605E5.2, IC2.3 (GND), IC2.5 (GND), IC2.21 (AGND), IC3.4 (COM), IC4.4 (COM), IC5.4 (COM), IC6.2 (GND), IC6.4 (GND), LED1.C, LED2.C, LED3.C, LED4.C, PAD1.1, Q4.1 (S), Q4.2 (S), Q4.3 (S), Q5.1 (S), Q5.2 (S), Q5.3 (S), Q6.1 (S), Q6.2 (S), Q6.3 (S), Q10.1 (S), Q10.2 (S), Q10.3 (S), Q11.1 (S), Q11.2 (S), Q11.3 (S), Q12.1 (S), Q12.2 (S), Q12.3 (S), Q16.1 (S), Q16.2 (S), Q16.3 (S), Q17.1 (S), Q17.2 (S), Q17.3 (S), Q18.1 (S), Q18.2 (S), Q18.3 (S), R5.1, R6.1, R9.1, R10.1, R13.1, R14.1, R20.2, R21.2, R22.2, R27.1, U$1.3, U$5.1
LED1: IC2.26 (PC3(ADC3)), R1.1
LED2: IC2.32 (PD2(INT0)), R2.1
LED3: IC2.11 (PD7(AIN1)), R3.1
MIDDLE: IC2.10 (PD6(AIN0)), R23.2, R24.2, R25.2
MISO/LED4: IC2.16 (PB4(MISO)), R4.1, U$5.2
MOSI: R29.2, U$5.10
unnamed: IC4.7 (HO), R11.1
unnamed: IC3.7 (HO), R7.1
unnamed: LED1.A, R1.2
unnamed: LED2.A, R2.2
unnamed: LED3.A, R3.2
unnamed: C13.2, IC2.20 (AREF)
unnamed: IC3.5 (LO), R8.1
unnamed: EFO-BM1605E5.1, IC2.7 (PB6(XTAL1/TOSC1))
unnamed: EFO-BM1605E5.3, IC2.8 (PB7(XTAL2/TOSC2))
unnamed: LED4.A, R4.2
unnamed: Q1.4 (G), Q2.4 (G), Q3.4 (G), R7.2
unnamed: C1.1, D1.1 (C), IC3.8 (VB)
unnamed: IC4.5 (LO), R12.1
unnamed: Q7.4 (G), Q8.4 (G), Q9.4 (G), R11.2
unnamed: Q4.4 (G), Q5.4 (G), Q6.4 (G), R8.2
unnamed: C2.1, D2.1 (C), IC4.8 (VB)
unnamed: Q10.4 (G), Q11.4 (G), Q12.4 (G), R12.2
unnamed: IC5.7 (HO), R15.1
unnamed: IC5.5 (LO), R16.1
unnamed: Q13.4 (G), Q14.4 (G), Q15.4 (G), R15.2
unnamed: C3.1, D3.1 (C), IC5.8 (VB)
unnamed: Q16.4 (G), Q17.4 (G), Q18.4 (G), R16.2
PHASE_A: C1.2, IC3.6 (VS), PAD3.1, Q1.1 (S), Q1.2 (S), Q1.3 (S), Q2.1 (S), Q2.2 (S), Q2.3 (S), Q3.1 (S), Q3.2 (S), Q3.3 (S), Q4.5 (D), Q4.6 (D), Q4.7 (D), Q4.8 (D), Q5.5 (D), Q5.6 (D), Q5.7 (D), Q5.8 (D), Q6.5 (D), Q6.6 (D), Q6.7 (D), Q6.8 (D), R17.2
PHASE_B: C2.2, IC4.6 (VS), PAD4.1, Q7.1 (S), Q7.2 (S), Q7.3 (S), Q8.1 (S), Q8.2 (S), Q8.3 (S), Q9.1 (S), Q9.2 (S), Q9.3 (S), Q10.5 (D), Q10.6 (D), Q10.7 (D), Q10.8 (D), Q11.5 (D), Q11.6 (D), Q11.7 (D), Q11.8 (D), Q12.5 (D), Q12.6 (D), Q12.7 (D), Q12.8 (D), R18.2
PHASE_C: C3.2, IC5.6 (VS), PAD5.1, Q13.1 (S), Q13.2 (S), Q13.3 (S), Q14.1 (S), Q14.2 (S), Q14.3 (S), Q15.1 (S), Q15.2 (S), Q15.3 (S), Q16.5 (D), Q16.6 (D), Q16.7 (D), Q16.8 (D), Q17.5 (D), Q17.6 (D), Q17.7 (D), Q17.8 (D), Q18.5 (D), Q18.6 (D), Q18.7 (D), Q18.8 (D), R19.2
PPM: IC2.12 (PB0(ICP)), U$5.7
RESET: IC2.29 (PC6(/RESET)), R28.2, U$5.6
RXD: IC2.30 (PD0(RXD)), U$5.3
SCK: IC2.17 (PB5(SCK)), U$5.4
SCL: IC2.28 (PC5(ADC5/SCL)), U$1.1
SDA: IC2.27 (PC4(ADC4/SDA)), U$1.2
TXD: IC2.31 (PD1(TXD)), U$5.8
V_BAT: IC2.19 (ADC6), R26.1, R27.2

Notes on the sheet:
Programmer/Seriell
Power
Microcontroller
Phase Drivers
License: CC-BY-SA 3.0 DE
http://creativecommons.org/licenses/by-sa/3.0/de/
LED Indicators
Commutation detection
open-blcd (C) 2008 Piotr Esden-Tempski <piotr at esden.net>

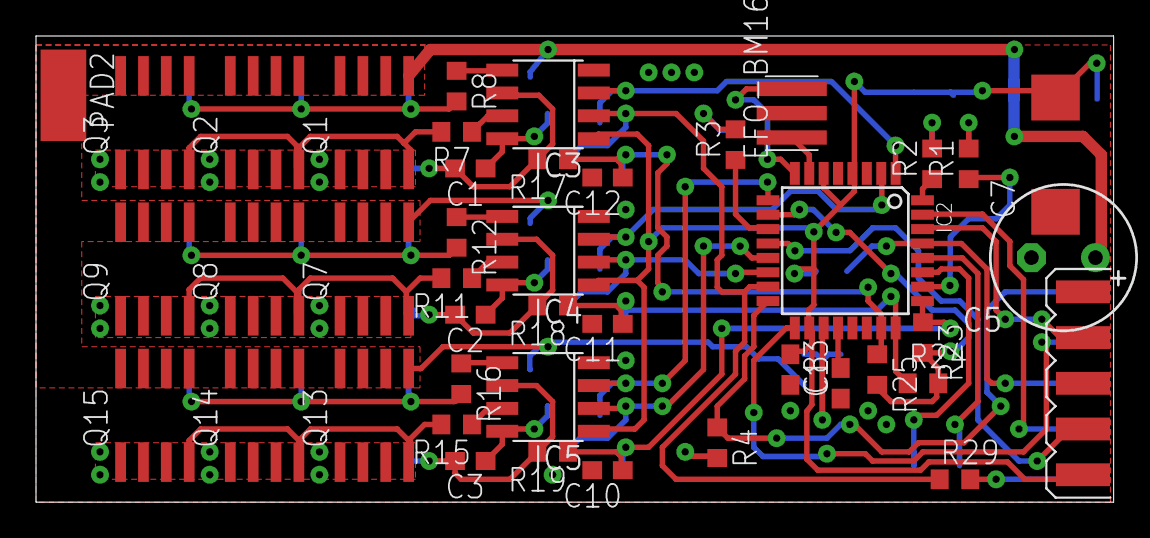
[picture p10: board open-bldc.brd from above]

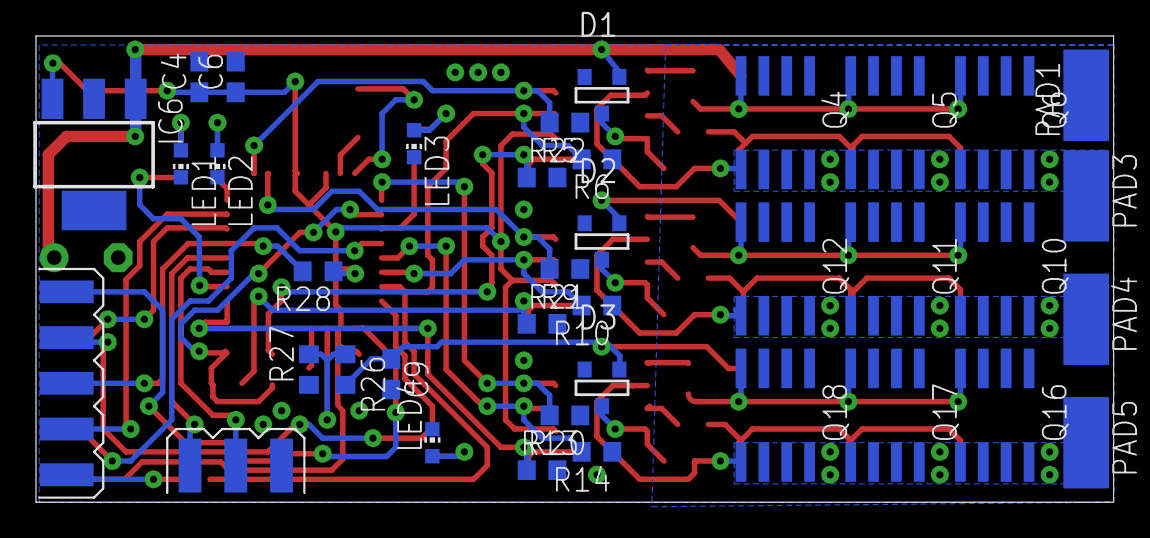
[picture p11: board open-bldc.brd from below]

Board: 2 copper layers, 59.9 x 25.9 mm, 80 parts (38 on the bottom side), 51 nets.

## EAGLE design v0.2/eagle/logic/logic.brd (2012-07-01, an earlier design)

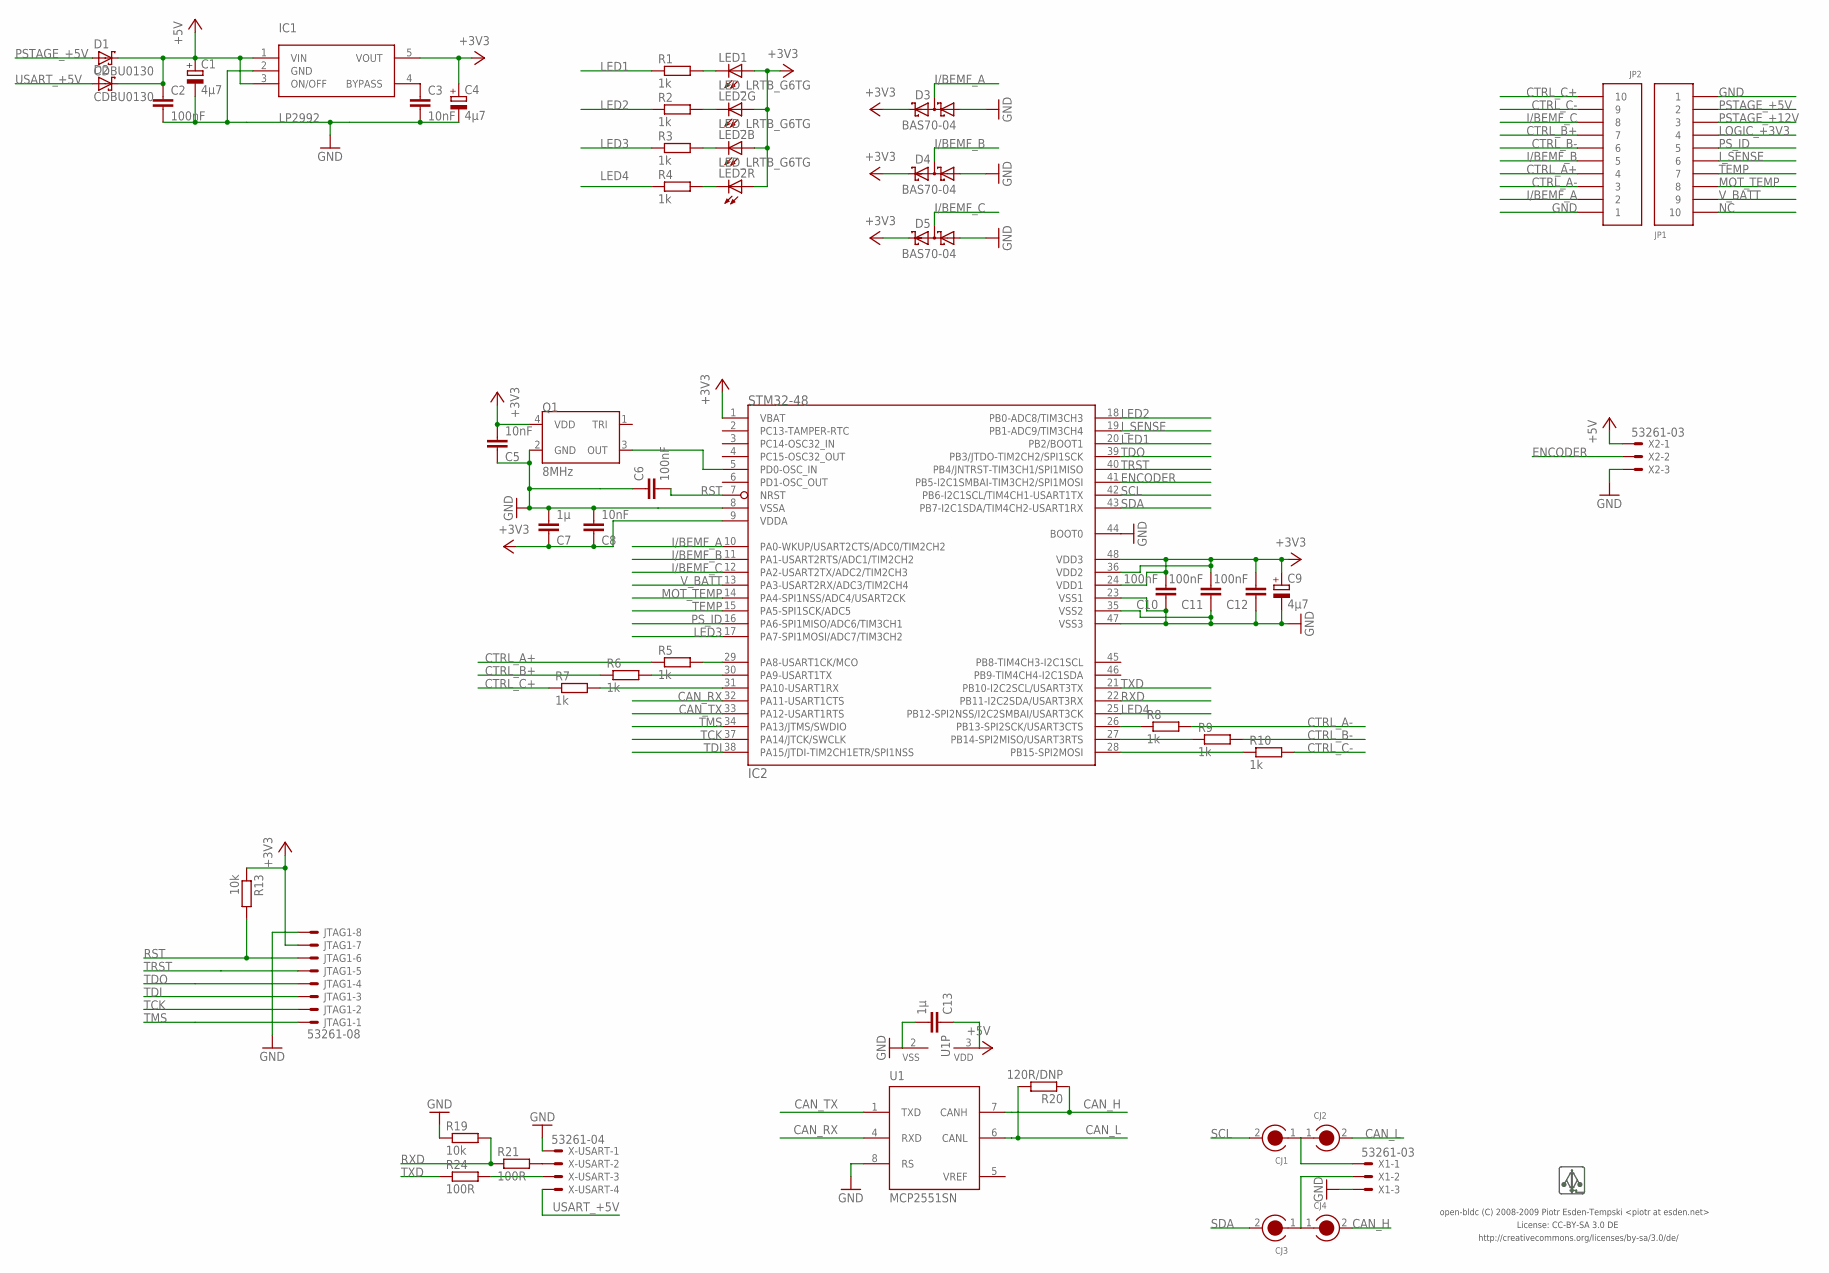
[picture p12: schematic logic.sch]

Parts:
C1, C4, C9: 4µ7; A/3216-18R
C2, C6, C10, C11, C12: 100nF; C0603
C3, C5, C8: 10nF; C0603
C7, C13: 1µ; C0603
CJ1, CJ2, CJ3, CJ4: CIRC_JMP
D1, D2: CDBU0130; SOD523
D3, D4, D5: BAS70-04; SOT23
IC1: LP2992; SOT23-5
IC2: STM32-48; LQFP48
JP1, JP2: PIN_HDR_1.27MM_10
JTAG1: 53261-08
LED1: AMBER; CHIP-LED0603
LED2: LED_LRTB_G6TG; PLCC6
Q1: 8MHz; ASE_OSCILLATOR
R1, R2, R3, R4, R5, R6, R7, R8, R9, R10: 1k; R0603
R13, R19: 10k; R0603
R20: 120R/DNP; R0603
R21, R24: 100R; R0603
U1: MCP2551SN; SO-08
U$1: LOGO
X1, X2: 53261-03
X-USART: 53261-04

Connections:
+3V3: C4.+, C5.2, C7.1, C8.1, C9.+, C10.2, C11.2, C12.2, D3.2 (C2), D4.2 (C2), D5.2 (C2), IC1.5 (VOUT), IC2.1 (VBAT), IC2.9 (VDDA), IC2.24 (VDD1), IC2.36 (VDD2), IC2.48 (VDD3), JTAG1.7, LED1.A, LED2.A1 (A), LED2.A2 (A), LED2.A3 (A), Q1.4 (VDD), R13.1
+5V: C1.+, C2.1, C13.1, D1.C, D2.C, IC1.1 (VIN), IC1.3 (ON/OFF), U1.3 (VDD), X2.1
CAN_H: CJ4.2, R20.1, U1.7 (CANH)
CAN_L: CJ2.2, R20.2, U1.6 (CANL)
CAN_RX: IC2.32 (PA11-USART1CTS), U1.4 (RXD)
CAN_TX: IC2.33 (PA12-USART1RTS), U1.1 (TXD)
CTRL_A+: JP2.P$4 (4), R5.1
CTRL_A-: JP2.P$3 (3), R8.2
CTRL_B+: JP2.P$7 (7), R6.1
CTRL_B-: JP2.P$6 (6), R9.2
CTRL_C+: JP2.P$10 (10), R7.1
CTRL_C-: JP2.P$9 (9), R10.2
ENCODER: IC2.41 (PB5-I2C1SMBAI-TIM3CH2/SPI1MOSI), X2.2
GND: C1.-, C2.2, C3.2, C4.-, C5.1, C6.1, C7.2, C8.2, C9.-, C10.1, C11.1, C12.1, C13.2, D3.1 (A1), D4.1 (A1), D5.1 (A1), IC1.2 (GND), IC2.8 (VSSA), IC2.23 (VSS1), IC2.35 (VSS2), IC2.44 (BOOT0), IC2.47 (VSS3), JP1.P$1 (1), JP2.P$1 (1), JTAG1.8, Q1.2 (GND), R19.1, U1.2 (VSS), U1.8 (RS), X1.3, X2.3, X-USART.1
I/BEMF_A: D3.3 (C1A2), IC2.10 (PA0-WKUP/USART2CTS/ADC0/TIM2CH2), JP2.P$2 (2)
I/BEMF_B: D4.3 (C1A2), IC2.11 (PA1-USART2RTS/ADC1/TIM2CH2), JP2.P$5 (5)
I/BEMF_C: D5.3 (C1A2), IC2.12 (PA2-USART2TX/ADC2/TIM2CH3), JP2.P$8 (8)
I_SENSE: IC2.19 (PB1-ADC9/TIM3CH4), JP1.P$6 (6)
LED1: IC2.20 (PB2/BOOT1), R1.1
LED2: IC2.18 (PB0-ADC8/TIM3CH3), R2.1
LED3: IC2.17 (PA7-SPI1MOSI/ADC7/TIM3CH2), R3.1
LED4: IC2.25 (PB12-SPI2NSS/I2C2SMBAI/USART3CK), R4.1
LOGIC_+3V3: JP1.P$4 (4)
MOT_TEMP: IC2.14 (PA4-SPI1NSS/ADC4/USART2CK), JP1.P$8 (8)
unnamed: CJ3.1, CJ4.1, X1.2
unnamed: CJ1.1, CJ2.1, X1.1
unnamed: LED1.C, R1.2
unnamed: LED2.C1 (C), R4.2
unnamed: LED2.C3 (C), R3.2
unnamed: R21.2, X-USART.2
unnamed: LED2.C2 (C), R2.2
unnamed: R24.2, X-USART.3
unnamed: C3.1, IC1.4 (BYPASS)
unnamed: IC2.26 (PB13-SPI2SCK/USART3CTS), R8.1
unnamed: IC2.27 (PB14-SPI2MISO/USART3RTS), R9.1
unnamed: IC2.28 (PB15-SPI2MOSI), R10.1
unnamed: IC2.5 (PD0-OSC_IN), Q1.3 (OUT)
unnamed: IC2.29 (PA8-USART1CK/MCO), R5.2
unnamed: IC2.30 (PA9-USART1TX), R6.2
unnamed: IC2.31 (PA10-USART1RX), R7.2
NC: JP1.P$10 (10)
PSTAGE_+5V: D1.A, JP1.P$2 (2)
PSTAGE_+12V: JP1.P$3 (3)
PS_ID: IC2.16 (PA6-SPI1MISO/ADC6/TIM3CH1), JP1.P$5 (5)
RST: C6.2, IC2.7 (NRST), JTAG1.6, R13.2
RXD: IC2.22 (PB11-I2C2SDA/USART3RX), R19.2, R21.1
SCL: CJ1.2, IC2.42 (PB6-I2C1SCL/TIM4CH1-USART1TX)
SDA: CJ3.2, IC2.43 (PB7-I2C1SDA/TIM4CH2-USART1RX)
TCK: IC2.37 (PA14/JTCK/SWCLK), JTAG1.2
TDI: IC2.38 (PA15/JTDI-TIM2CH1ETR/SPI1NSS), JTAG1.3
TDO: IC2.39 (PB3/JTDO-TIM2CH2/SPI1SCK), JTAG1.4
TEMP: IC2.15 (PA5-SPI1SCK/ADC5), JP1.P$7 (7)
TMS: IC2.34 (PA13/JTMS/SWDIO), JTAG1.1
TRST: IC2.40 (PB4/JNTRST-TIM3CH1/SPI1MISO), JTAG1.5
TXD: IC2.21 (PB10-I2C2SCL/USART3TX), R24.1
USART_+5V: D2.A, X-USART.4
VREF: U1.5 (VREF)
V_BATT: IC2.13 (PA3-USART2RX/ADC3/TIM2CH4), JP1.P$9 (9)

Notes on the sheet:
License: CC-BY-SA 3.0 DE
http://creativecommons.org/licenses/by-sa/3.0/de/
open-bldc (C) 2008-2009 Piotr Esden-Tempski <piotr at esden.net>



Board: 4 copper layers, 45.5 x 21.0 mm, 50 parts (28 on the bottom side), 54 nets.

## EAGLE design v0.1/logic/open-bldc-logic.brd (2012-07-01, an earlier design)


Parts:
+: BATT+; SMD2,54-5,08
-: BATT-; SMD2,54-5,08
C4, C12, C36: 10nF; C0603
C6, C14, C32, C33, C34: 100nF; C0603
C7, C35, C42: 4µ7; A/3216-18R
C8: 1µ; A/3216-18R
C9: 100n; C0603
C17, C18: 47p; C0603
C31: 100µ; D/7343-31R
C37: 1µ; C0603
D4, D5, D6: BAS70-04; SOT23
D7: BAS21; SOT-23
I2C: PIN_HDR_EDG_1.27MM_3-1
IC2: LP2992; SOT23-5
IC6: 5V vreg; SOT223
IC8: STM32-48; LQFP48
JP11, JP12: PIN_HDR_1.27MM_10
JTAG: PIN_HDR_EDG_1.27MM_5-2
LED1: AMBER; CHIP-LED0603
LED5: LED_LRTB_G6TG; PLCC6
Q7: 8MHz; ASE_OSCILLATOR
R3, R6, R9, R10, R13, R14, R25: 10k; R0603
R4, R5: 100R; R0603
R34, R35: 22; R0603
R36: 1k5; R0603
R37, R38, R39, R40, R47, R48: 1k; R0603
RN1: 1k; R4N1206
SJ1: SJ1S
SJ5: SJ2S
U3: ZX62-B-5PA
U4: MCP6004; TSSOP_14
X-USART: 53261-04

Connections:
+3V3: C7.+, C12.2, C32.2, C33.2, C34.2, C35.+, C36.1, C37.1, D4.2 (C2), D5.2 (C2), D6.2 (C2), IC2.5 (VOUT), IC8.1 (VBAT), IC8.9 (VDDA), IC8.24 (VDD1), IC8.36 (VDD2), IC8.48 (VDD3), JP12.P$4 (4), JTAG.P$2 (2), LED1.A, LED5.A1 (A), LED5.A2 (A), LED5.A3 (A), Q7.4 (VDD), R6.1, R9.1, R10.2, R13.2, R14.2, R25.2, R36.1, SJ5.3, U4.4 (V+)
+5V: C6.1, C8.+, C42.+, D7.1 (C), IC2.1 (VIN), IC2.3 (ON/OFF), IC6.3 (OUT), JP12.P$2 (2), SJ1.1, SJ5.1
+12V: +.1, C9.1, C31.+, IC6.1 (IN), JP12.P$3 (3)
BUF_I/BEMF_A: IC8.10 (PA0-WKUP/USART2CTS/ADC0/TIM2CH2), U4.13 (-IN), U4.14 (OUT)
BUF_I/BEMF_B: IC8.11 (PA1-USART2RTS/ADC1/TIM2CH2), U4.8 (OUT), U4.9 (-IN)
BUF_I/BEMF_C: IC8.12 (PA2-USART2TX/ADC2/TIM2CH3), U4.6 (-IN), U4.7 (OUT)
BUF_I_SENSE: IC8.19 (PB1-ADC9/TIM3CH4), U4.1 (OUT), U4.2 (-IN)
CTRL_A+: JP11.P$4 (4), R40.1
CTRL_A-: JP11.P$3 (3), R37.2
CTRL_B+: JP11.P$7 (7), R47.1
CTRL_B-: JP11.P$6 (6), R38.2
CTRL_C+: JP11.P$10 (10), R48.1
CTRL_C-: JP11.P$9 (9), R39.2
GND: -.1, C4.2, C6.2, C7.-, C8.-, C9.2, C12.1, C14.1, C17.2, C18.2, C31.-, C32.1, C33.1, C34.1, C35.-, C36.2, C37.2, C42.-, D4.1 (A1), D5.1 (A1), D6.1 (A1), I2C.P$3 (3), IC2.2 (GND), IC6.2 (GND), IC6.4 (GND), IC8.8 (VSSA), IC8.23 (VSS1), IC8.35 (VSS2), IC8.44 (BOOT0), IC8.47 (VSS3), JP11.P$1 (1), JP12.P$1 (1), JTAG.P$6 (6), JTAG.P$8 (8), JTAG.P$10 (10), Q7.2 (GND), R3.1, U3.GND_LEFT (S1), U3.GND_RIGHT (S2), U3.GND_UP_LEFT (S3), U3.GND_UP_RIGHT (S4), U3.PIN_4 (4), U4.11 (V-), X-USART.1
I/BEMF_A: D4.3 (C1A2), JP11.P$2 (2), U4.12 (+IN)
I/BEMF_B: D5.3 (C1A2), JP11.P$5 (5), U4.10 (+IN)
I/BEMF_C: D6.3 (C1A2), JP11.P$8 (8), U4.5 (+IN)
I_SENSE: JP12.P$6 (6), U4.3 (+IN)
LED1: IC8.20 (PB2/BOOT1), RN1.1
LED2: IC8.18 (PB0-ADC8/TIM3CH3), RN1.3 (1)
LED3: IC8.17 (PA7-SPI1MOSI/ADC7/TIM3CH2), RN1.5 (1)
LED4: IC8.25 (PB12-SPI2NSS/I2C2SMBAI/USART3CK), RN1.7 (1)
MOT_TEMP: IC8.14 (PA4-SPI1NSS/ADC4/USART2CK), JP12.P$8 (8)
unnamed: IC8.29 (PA8-USART1CK/MCO), R40.2
unnamed: LED5.C1 (C), RN1.8 (2)
unnamed: LED1.C, RN1.2
unnamed: LED5.C3 (C), RN1.6 (2)
unnamed: LED5.C2 (C), RN1.4 (2)
unnamed: IC8.26 (PB13-SPI2SCK/USART3CTS), R37.1
unnamed: SJ5.2, X-USART.4
unnamed: R4.2, X-USART.2
unnamed: R5.2, X-USART.3
unnamed: C4.1, IC2.4 (BYPASS)
unnamed: R34.1, U3.PIN_2 (2)
unnamed: SJ1.2, U3.PIN_5 (5)
unnamed: R35.1, R36.2, U3.PIN_3 (3)
unnamed: IC8.27 (PB14-SPI2MISO/USART3RTS), R38.1
unnamed: IC8.28 (PB15-SPI2MOSI), R39.1
unnamed: IC8.5 (PD0-OSC_IN), Q7.3 (OUT)
unnamed: IC8.30 (PA9-USART1TX), R47.2
unnamed: IC8.31 (PA10-USART1RX), R48.2
NC: JP12.P$10 (10)
PS_ID: IC8.16 (PA6-SPI1MISO/ADC6/TIM3CH1), JP12.P$5 (5)
RST: C14.2, IC8.7 (NRST), JTAG.P$3 (3), R13.1
RXD: IC8.22 (PB11-I2C2SDA/USART3RX), R3.2, R4.1
SCL: I2C.P$1 (1), IC8.42 (PB6-I2C1SCL/TIM4CH1-USART1TX)
SDA: I2C.P$2 (2), IC8.43 (PB7-I2C1SDA/TIM4CH2-USART1RX)
TCK: IC8.37 (PA14/JTCK/SWCLK), JTAG.P$7 (7), R9.2
TDI: IC8.38 (PA15/JTDI-TIM2CH1ETR/SPI1NSS), JTAG.P$1 (1), R14.1
TDO: IC8.39 (PB3/JTDO-TIM2CH2/SPI1SCK), JTAG.P$9 (9), R6.2
TEMP: IC8.15 (PA5-SPI1SCK/ADC5), JP12.P$7 (7)
TMS: IC8.34 (PA13/JTMS/SWDIO), JTAG.P$5 (5), R10.1
TRST: IC8.40 (PB4/JNTRST-TIM3CH1/SPI1MISO), JTAG.P$4 (4), R25.1
TXD: IC8.21 (PB10-I2C2SCL/USART3TX), R5.1
USB_+5V: D7.3 (A), U3.PIN_1 (1)
USB_DM: C18.1, IC8.32 (PA11-USART1CTS), R34.2
USB_DP: C17.1, IC8.33 (PA12-USART1RTS), R35.2
V_BATT: IC8.13 (PA3-USART2RX/ADC3/TIM2CH4), JP12.P$9 (9)

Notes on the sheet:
Power
Microcontroller
License: CC-BY-SA 3.0 DE
http://creativecommons.org/licenses/by-sa/3.0/de/
LED Indicators
open-bldc (C) 2008-2009 Piotr Esden-Tempski <piotr at esden.net>
Logic



Board: 2 copper layers, 45.5 x 21.0 mm, 57 parts (32 on the bottom side), 57 nets.

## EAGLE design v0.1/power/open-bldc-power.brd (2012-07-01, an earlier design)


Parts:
ACS1, ACS2, ACS3, ACS712: ACS712; SO8
C1, C2, C3: 10µ; A/3216-18R
C4, C38, C39: 100µ; D/7343-31R
C10, C19, C22, C25, C28, C29, C30, C40: 100n; C0603
C11, C13, C15, C16, C20, C23, C26: 1n; C0603
C41: optional; E5-6
C43, C44, C45: 22n; C0603
C46: 4µ7; A/3216-18R
D1, D2, D3: BAS21; SOT-23
IC3, IC4, IC5: IR2101; SO-8
IC7: ST662A; SO8
JP21, JP22: PIN_HDR_1.27MM_10
PAD3: PHASE_A; SMD2,54-5,08
PAD4: PHASE_B; SMD2,54-5,08
PAD5: PHASE_C; SMD2,54-5,08
PAD6: BATT+; SMD2,54-5,08
PAD7: BATT-; SMD2,54-5,08
Q1, Q2, Q3, Q4, Q5, Q6: IRF3704S; D2PACK
R1: NP; R0603
R2: 0; R0603
R7, R8, R11, R12, R15: 22; R0603
R16: R22; R0603
R17, R19, R21, R24, R26, R28, R29, R30, R31, R32, R33, R42, R44, R46: 10k; R0603
R18, R20, R22: 3k6; R0603
R23, R41, R43, R45: 2k; R0603
R27: 2k7; R0603
SJ2, SJ3, SJ4, SJ10: SJ2S

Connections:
+3V3: JP22.P$4 (4), R1.2
+5V: ACS1.8 (VCC), ACS2.8 (VCC), ACS3.8 (VCC), ACS712.8 (VCC), C10.1, C19.1, C22.1, C25.1, C45.2, IC7.5 (VCC), JP22.P$2 (2)
+12V: ACS712.1 (IP+_1), ACS712.2 (IP+_2), C38.+, C39.+, C40.1, C41.+, D1.3 (A), D2.3 (A), D3.3 (A), JP22.P$3 (3), PAD6.1, R26.2, SJ10.1
+12V_I_SENSE: ACS712.3 (IP-_1), ACS712.4 (IP-_2), Q1.2 (D), Q3.2 (D), Q5.2 (D)
BEMF_A: C15.1, R17.2, R18.1, SJ2.1
BEMF_B: C13.1, R19.2, R20.1, SJ3.1
BEMF_C: C16.1, R21.2, R22.1, SJ4.1
CTRL_A+: IC3.2 (HIN), JP21.P$4 (4), R29.1
CTRL_A-: IC3.3 (LIN), JP21.P$3 (3), R28.1
CTRL_B+: IC4.2 (HIN), JP21.P$7 (7), R31.1
CTRL_B-: IC4.3 (LIN), JP21.P$6 (6), R30.1
CTRL_C+: IC5.2 (HIN), JP21.P$10 (10), R33.1
CTRL_C-: IC5.3 (LIN), JP21.P$9 (9), R32.1
GND: ACS1.5 (GND), ACS2.5 (GND), ACS3.5 (GND), ACS712.5 (GND), C4.-, C10.2, C11.2, C13.2, C15.2, C16.2, C19.2, C20.2, C22.2, C23.2, C25.2, C26.2, C28.2, C29.2, C30.2, C38.-, C39.-, C40.2, C41.-, C46.-, IC3.4 (COM), IC4.4 (COM), IC5.4 (COM), IC7.7 (GND), IC7.8 (SHDN), JP21.P$1 (1), JP22.P$1 (1), PAD7.1, Q2.3 (S), Q4.3 (S), Q6.3 (S), R2.1, R18.2, R20.2, R22.2, R24.2, R27.1, R28.2, R29.2, R30.2, R31.2, R32.2, R33.2, R42.2, R44.2, R46.2
I/BEMF_A: JP21.P$2 (2), SJ2.2
I/BEMF_B: JP21.P$5 (5), SJ3.2
I/BEMF_C: JP21.P$8 (8), SJ4.2
I_A: R41.1, R42.1, SJ2.3
I_B: R43.1, R44.1, SJ3.3
I_C: R45.1, R46.1, SJ4.3
I_PHASE_A: ACS1.3 (IP-_1), ACS1.4 (IP-_2), PAD3.1
I_PHASE_B: ACS2.3 (IP-_1), ACS2.4 (IP-_2), PAD4.1
I_PHASE_C: ACS3.3 (IP-_1), ACS3.4 (IP-_2), PAD5.1
I_SENSE: JP22.P$6 (6), R23.1, R24.1
MOT_TEMP: JP22.P$8 (8)
unnamed: IC4.7 (HO), R11.1
unnamed: IC3.7 (HO), R7.1
unnamed: ACS712.7 (VIOUT), R23.2
unnamed: IC3.5 (LO), R8.1
unnamed: Q1.1 (G), R7.2
unnamed: C1.+, D1.1 (C), IC3.8 (VB)
unnamed: IC4.5 (LO), R12.1
unnamed: Q3.1 (G), R11.2
unnamed: Q5.1 (G), R15.2
unnamed: C2.+, D2.1 (C), IC4.8 (VB)
unnamed: Q6.1 (G), R16.2
unnamed: IC5.7 (HO), R15.1
unnamed: IC5.5 (LO), R16.1
unnamed: C3.+, D3.1 (C), IC5.8 (VB)
unnamed: ACS712.6 (FILTER), C11.1
unnamed: C43.2, IC7.1 (C1-)
unnamed: C44.2, IC7.3 (C2-)
unnamed: C43.1, IC7.2 (C1+)
unnamed: C44.1, IC7.4 (C2+)
unnamed: ACS1.6 (FILTER), C20.1
unnamed: ACS1.7 (VIOUT), R41.2
unnamed: ACS2.6 (FILTER), C23.1
unnamed: ACS2.7 (VIOUT), R43.2
unnamed: ACS3.6 (FILTER), C26.1
unnamed: ACS3.7 (VIOUT), R45.2
unnamed: Q2.1 (G), R8.2
unnamed: Q4.1 (G), R12.2
NC: JP22.P$10 (10)
PHASE_A: ACS1.1 (IP+_1), ACS1.2 (IP+_2), C1.-, IC3.6 (VS), Q1.3 (S), Q2.2 (D), R17.1
PHASE_B: ACS2.1 (IP+_1), ACS2.2 (IP+_2), C2.-, IC4.6 (VS), Q3.3 (S), Q4.2 (D), R19.1
PHASE_C: ACS3.1 (IP+_1), ACS3.2 (IP+_2), C3.-, IC5.6 (VS), Q5.3 (S), Q6.2 (D), R21.1
PS_ID: JP22.P$5 (5), R1.1, R2.2
TEMP: JP22.P$7 (7)
VBD: C4.+, C28.1, C29.1, C30.1, IC3.1 (VCC), IC4.1 (VCC), IC5.1 (VCC), SJ10.2
VBD_PUMP: C45.1, C46.+, IC7.6 (VOUT), SJ10.3
V_BATT: JP22.P$9 (9), R26.1, R27.2

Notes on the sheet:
Phase Drivers
License: CC-BY-SA 3.0 DE
http://creativecommons.org/licenses/by-sa/3.0/de/
Commutation detection
open-bldc (C) 2008-2009 Piotr Esden-Tempski <piotr at esden.net>
Powerstage



Board: 2 copper layers, 45.5 x 44.3 mm, 84 parts (17 on the bottom side), 58 nets.

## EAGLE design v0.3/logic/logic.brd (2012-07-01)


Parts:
C1, C4, C9: 4µ7; 0603-CAP
C2, C6, C10, C11, C12: 100nF; 0603-CAP
C3, C5, C8: 10nF; 0603-CAP
C7, C13: 1µ; 0603-CAP
D1, D2, D6: CDBU0130; 0603-LED
D3, D4, D5: BAS70-04; SOT23
IC1: LP2992; SOT23-5
IC2: STM32-48; LQFP48
IC3: SN65HVD230; SO8
J1, J2: CIRC_JMP_2
JP1: PIN_HDR_EDG_1.27MM_5-2-DH; PIN_HDR_1.27MM_SMD_DH_10
LED1: AMBER; 0603-LED
LED2: LED_LRTB_G6TG; PLCC6
OBC1: OBLDC_CONN-1.27MM; OBLDC_CONN
Q1: 8MHz; ASE_OSCILLATOR
R1, R2, R3, R4, R5, R6, R7, R8, R9, R10: 1k; 0603-RES
R11, R12, R13, R17, R19, R22, R26, R27, R29, R32, R34: 10k; 0603-RES
R14, R15, R16, R23, R25, R28, R30, R33, R35: 19k1; 0603-RES
R18: 4k87; 0603-RES
R20: 120R/DNP; 0603-RES
R21, R24: 100R; 0603-RES
R31: 0, 10k-100k; 0603-RES
TP_LEDA: TP-SMD; MINI_TESTPAD
TP_LEDB: TP-SMD; MINI_TESTPAD
TP_LEDG: TP-SMD; MINI_TESTPAD
TP_LEDR: TP-SMD; MINI_TESTPAD
U$1: LOGO
X1, X2, X3: CONN_4-1-53261; PB-53261-04

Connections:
+3V3: C4.P$1 (1), C5.P$2 (2), C7.P$1 (1), C8.P$1 (1), C9.P$1 (1), C10.P$2 (2), C11.P$2 (2), C12.P$2 (2), C13.P$1 (1), D3.2 (C2), D4.2 (C2), D5.2 (C2), IC1.5 (VOUT), IC2.1 (VBAT), IC2.9 (VDDA), IC2.24 (VDD1), IC2.36 (VDD2), IC2.48 (VDD3), IC3.3 (VCC), JP1.1, LED1.A, LED2.A1 (A), LED2.A2 (A), LED2.A3 (A), OBC1.13 (+3.3V), Q1.4 (VDD)
+5V: C1.P$1 (1), C2.P$1 (1), D1.C, D2.C, D6.C, IC1.1 (VIN), IC1.3 (ON/OFF), X1.4
+5V_LOGIC_SUPP: D1.A, OBC1.12 (+5V)
ATTN_BATTERY+: IC2.13 (PA3-USART2RX/ADC3/TIM2CH4), R17.P$2 (2), R18.P$1 (1)
ATTN_ENCODER_A: IC2.16 (PA6-SPI1MISO/ADC6/TIM3CH1), R34.P$2 (2), R35.P$1 (1)
ATTN_ENCODER_B: IC2.17 (PA7-SPI1MOSI/ADC7/TIM3CH2), R32.P$2 (2), R33.P$1 (1)
ATTN_GLOBAL_CURRENT: IC2.19 (PB1-ADC9/TIM3CH4), R22.P$2 (2), R23.P$1 (1)
ATTN_STAR_VOLTAGE: IC2.14 (PA4-SPI1NSS/ADC4/USART2CK), R29.P$2 (2), R30.P$1 (1)
ATTN_U_CURRENT: IC2.18 (PB0-ADC8/TIM3CH3), R27.P$2 (2), R28.P$1 (1)
ATTN_U_VOLTAGE: D3.3 (C1A2), IC2.10 (PA0-WKUP/USART2CTS/ADC0/TIM2CH2), R13.P$2 (2), R16.P$1 (1)
ATTN_V_CURRENT: IC2.15 (PA5-SPI1SCK/ADC5), R25.P$1 (1), R26.P$2 (2)
ATTN_V_VOLTAGE: D4.3 (C1A2), IC2.11 (PA1-USART2RTS/ADC1/TIM2CH2), R11.P$2 (2), R15.P$1 (1)
ATTN_W_VOLTAGE: D5.3 (C1A2), IC2.12 (PA2-USART2TX/ADC2/TIM2CH3), R12.P$2 (2), R14.P$1 (1)
BATTERY+: OBC1.20 (BAT+), R17.P$1 (1)
CAN_+5V: D6.A, X3.4
CAN_H: IC3.7 (CANH), J2.3, R20.P$1 (1)
CAN_L: IC3.6 (CANL), J1.3, R20.P$2 (2)
CAN_RX: IC2.32 (PA11-USART1CTS), IC3.4 (RXD)
CAN_SLP: IC2.41 (PB5-I2C1SMBAI-TIM3CH2/SPI1MOSI), R31.P$1 (1)
CAN_TX: IC2.33 (PA12-USART1RTS), IC3.1 (TXD)
ENCODER_A: R34.P$1 (1), X1.3
ENCODER_B: R32.P$1 (1), X1.2
EXT_SCL: IC2.45 (PB8-TIM4CH3-I2C1SCL), J1.1
EXT_SDA: IC2.46 (PB9-TIM4CH4-I2C1SDA), J2.1
GLOBAL_CURRENT: OBC1.17 (GC), R22.P$1 (1)
GND: C1.P$2 (2), C2.P$2 (2), C3.P$2 (2), C4.P$2 (2), C5.P$1 (1), C6.P$1 (1), C7.P$2 (2), C8.P$2 (2), C9.P$2 (2), C10.P$1 (1), C11.P$1 (1), C12.P$1 (1), C13.P$2 (2), D3.1 (A1), D4.1 (A1), D5.1 (A1), IC1.2 (GND), IC2.8 (VSSA), IC2.23 (VSS1), IC2.35 (VSS2), IC2.44 (BOOT0), IC2.47 (VSS3), IC3.2 (GND), JP1.3, JP1.5, JP1.7, JP1.9, OBC1.1 (GND), OBC1.11 (GND), Q1.2 (GND), R14.P$2 (2), R15.P$2 (2), R16.P$2 (2), R18.P$2 (2), R19.P$1 (1), R23.P$2 (2), R25.P$2 (2), R28.P$2 (2), R30.P$2 (2), R33.P$2 (2), R35.P$2 (2), X1.1, X2.1, X3.1
LEDA: IC2.20 (PB2/BOOT1), R1.P$1 (1), TP_LEDA.1
LEDB: IC2.2 (PC13-TAMPER-RTC), R3.P$1 (1), TP_LEDB.1
LEDG: IC2.3 (PC14-OSC32_IN), R2.P$1 (1), TP_LEDG.1
LEDR: IC2.25 (PB12-SPI2NSS/I2C2SMBAI/USART3CK), R4.P$1 (1), TP_LEDR.1
unnamed: J2.2, X3.3
unnamed: J1.2, X3.2
unnamed: LED1.C, R1.P$2 (2)
unnamed: LED2.C1 (C), R4.P$2 (2)
unnamed: LED2.C3 (C), R3.P$2 (2)
unnamed: R21.P$2 (2), X2.2
unnamed: IC3.8 (RS), R31.P$2 (2)
unnamed: LED2.C2 (C), R2.P$2 (2)
unnamed: R24.P$2 (2), X2.3
unnamed: C3.P$1 (1), IC1.4 (BYPASS)
unnamed: IC2.26 (PB13-SPI2SCK/USART3CTS), R8.P$1 (1)
unnamed: IC2.27 (PB14-SPI2MISO/USART3RTS), R9.P$1 (1)
unnamed: IC2.28 (PB15-SPI2MOSI), R10.P$1 (1)
unnamed: IC2.5 (PD0-OSC_IN), Q1.3 (OUT)
unnamed: IC2.29 (PA8-USART1CK/MCO), R5.P$2 (2)
unnamed: IC2.30 (PA9-USART1TX), R6.P$2 (2)
unnamed: IC2.31 (PA10-USART1RX), R7.P$2 (2)
PHASE_U_CURRENT: OBC1.16 (PCU), R27.P$1 (1)
PHASE_U_HIGH: OBC1.4 (UH), R5.P$1 (1)
PHASE_U_LOW: OBC1.3 (UL), R8.P$2 (2)
PHASE_U_VOLTAGE: OBC1.2 (PVU), R13.P$1 (1)
PHASE_V_CURRENT: OBC1.15 (PCV), R26.P$1 (1)
PHASE_V_HIGH: OBC1.7 (VH), R6.P$1 (1)
PHASE_V_LOW: OBC1.6 (VL), R9.P$2 (2)
PHASE_V_VOLTAGE: OBC1.5 (PVV), R11.P$1 (1)
PHASE_W_HIGH: OBC1.10 (WH), R7.P$1 (1)
PHASE_W_LOW: OBC1.9 (WL), R10.P$2 (2)
PHASE_W_VOLTAGE: OBC1.8 (PVW), R12.P$1 (1)
PS_SCL: IC2.21 (PB10-I2C2SCL/USART3TX), OBC1.19 (SCL)
PS_SDA: IC2.22 (PB11-I2C2SDA/USART3RX), OBC1.18 (SDA)
RST: C6.P$2 (2), IC2.7 (NRST), JP1.10
RXD: IC2.43 (PB7-I2C1SDA/TIM4CH2-USART1RX), R19.P$2 (2), R21.P$1 (1)
STAR_VOLTAGE: OBC1.14 (SV), R29.P$1 (1)
TCK: IC2.37 (PA14/JTCK/SWCLK), JP1.4
TDI: IC2.38 (PA15/JTDI-TIM2CH1ETR/SPI1NSS), JP1.8
TDO: IC2.39 (PB3/JTDO-TIM2CH2/SPI1SCK), JP1.6
TMS: IC2.34 (PA13/JTMS/SWDIO), JP1.2
TXD: IC2.42 (PB6-I2C1SCL/TIM4CH1-USART1TX), R24.P$1 (1)
USART_+5V: D2.A, X2.4

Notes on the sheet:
License: CC-BY-SA 3.0 DE
http://creativecommons.org/licenses/by-sa/3.0/de/
open-bldc (C) 2008-2009 Piotr Esden-Tempski <piotr at esden.net>,
2010 Tom Ituarte <tomituarte@jobyenergy.com>



Board: 4 copper layers, 45.5 x 21.0 mm, 72 parts (36 on the bottom side), 69 nets.

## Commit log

2012-07-01 Initial repository split commit. For history before that refer to the master open-bldc repository.
    [clogic.brd, clogic.sch, cpico_power.brd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]
2012-07-01 Initial commit of the newest and shiniest low cost low power hardware!
    [strip.brd, strip.sch]
2012-07-06 More work on strip. Preliminary routing of the power stage.
    [strip.brd, strip.sch]
2012-07-08 Logic is on real GND now not pstage GND, to prevent current related logic signal bouncing. Added mounting holes.
    [strip.brd, strip.sch]
2012-07-10 Some more routing on strip. Connected all the control and feedback signals from the powerstage to the MCU.
    [strip.brd, strip.sch]
2012-07-11 All airwires routed. Now polishing can begin.
    [strip.brd, strip.sch]
2012-07-14 Added power rail tantalum capacitor.
    [strip.brd, strip.sch]
2012-07-15 Added silkscreen obldc logo. Put the logo and text on the pcb.
    [strip.brd, strip.sch]
2012-07-15 Corrected size of the 4.7uF capacitor for the STM32.
    [strip.brd, strip.sch]
2012-08-01 Some minor silkscreen polishing.
    [strip.brd]
2012-08-01 Placed part names for placement plan.
    [strip.brd]
2012-08-18 Added 3v3 CAN transceiver footprint to the strip.
    [strip.brd, strip.sch]
2012-08-18 Updated povray files with the CAN transceiver fitted.
    [strip.brd]
2012-08-19 Added gerber generation files.
    [layout.cfg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]
2012-08-19 Added jumper to (dis)connect BUSS+ and V_IN.
    [strip.brd, strip.sch]
2012-08-20 Extended the mounting tabs to provide 4 holes. Added VScoring for removable mounting tabs.
    [strip.brd]
2012-08-20 Some minor adjustments and cleanups.
    - Vias in hex pattern
    - Board .5mm wider for more material between mounting holes and board
    edge.
    - Adjusted pours to use more board real estate for more copper in board.
    [strip.brd]
2012-08-20 Some more layout polishing.
    [strip.brd]
2012-08-20 Swapped + - wires to be the right color.
2012-08-20 Made wire display switchable.
2012-08-20 Updated pov file to the newest board version.
2012-08-20 Added panel rail files.
    [rail.brd, rail.sch, strip.brd]
2012-08-20 Updated/improved gerber generation files.
    [layout.cfg]
2012-08-20 Added tabs for panelization.
    [strip.brd]
2012-09-27 Removed tabbing on the rails.
    [rail.brd]
2012-09-27 More work on the BOM and part documentation.
    [strip.brd, strip.sch]
2012-09-28 Increased size and spacing of mouse bites.
    [strip.brd]
2012-09-28 Cleaned up some remaining placement plan labels.
    [strip.brd]
2012-10-01 Fab files not needed any more as of Eagle 5. Added option for gerbmerge to disable drill size clustering!
    [layout.cfg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]
2012-10-01 Added some more documentation to the schematic.
    [strip.sch]
2012-10-08 Added more bom part number attributes.
    [strip.brd, strip.sch]
2012-10-10 Added 2x5 panel version with top/bottom horizontal rails.
    [layout.cfg, rail-h.brd, rail-h.sch]
2012-10-10 Corrected position of vscore.
    [strip.brd]

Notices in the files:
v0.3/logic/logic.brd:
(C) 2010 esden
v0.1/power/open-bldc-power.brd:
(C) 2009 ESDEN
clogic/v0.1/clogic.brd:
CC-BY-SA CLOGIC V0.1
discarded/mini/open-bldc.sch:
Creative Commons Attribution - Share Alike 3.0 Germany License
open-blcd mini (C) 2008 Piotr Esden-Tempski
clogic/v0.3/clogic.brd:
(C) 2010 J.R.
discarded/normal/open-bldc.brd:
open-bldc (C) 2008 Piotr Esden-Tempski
